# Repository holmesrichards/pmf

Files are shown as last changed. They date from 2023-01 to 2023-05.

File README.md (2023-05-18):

# Pole mixing filter

This is a multimode VCF in Kosmo format based on a [design](https://electricdruid.net/multimode-filters-part-2-pole-mixing-filters) by Electric Druid (ED). It uses pole mixing to achieve multiple filter behaviors.

## Design notes

### Changes from ED design

* 82k resistors (RF) changed to 100k; 91k resistors (RC) to fixed + trimmer.
* Added AC coupling capacitor on input signal to resonance compensation mixer.
* Added resistor on resonance input pin missing from original schematics. Changed its value from 51k to 120k.
* Added op amp buffers and pulldown resistors on LP1–4 after AC coupling capacitors.
* Added second inverting stage on input. Reduced first stage gain to 0.51 and increased output stage gain by the same factor.
* Changed ordering of 1st to 6th mixes.
* In 4P HP mix, changed 4.99k resistor to sum of 2k and 3k.
* Changed BP resistors for unity gain at peak.
* Changed 7th mix to {1, 2, 2, 0, 0} notch.
* Original had incorrect resistances for 8th mix; fixed.
* 7th and 8th mix have enough resistor footprints to implement any desired mix.
* Multiplexer replaced with rotary switch.
* Added header for expansion.

### Discussion

As discussed [here](Docs/tolerances.md), it is important that filter stages have unity DC gain and mixer ratios be correct at a level of about 1% or better, preferably more like 0.1% for the mixer resistors.

The 82k feedback resistors used in the ED design are a puzzle: Per the CEM3320 datasheet, they result in a gain of around 0.82. In the datasheet circuit these resistors are 100k giving gain 0.999. On the breadboard I found some gain variation (even if I matched the resistors), so I replaced the 91k resistors (RI, RC) with fixed + trimmer combinations.

If there is a DC offset on the input signal (if for instance it goes 0 to 5 V), then, due to its being DC coupled to the resonance compensation mixer, turning up the resonance CV would drive the DC offset of the output signal higher. Even with a 0 to 2 V input, the output could exceed 9 V due to the large offset. This is too large: With Vcc = 12 V, maximum output before clipping is about 9 V. Adding a capacitor to AC couple the input signal to the compensation mixer eliminates this problem.

The ED schematics omit a resistor on the resonance input pin. In the comments Tom Wiltshire says this should be 51k. I found this value would cause self oscillation to start up at a very low position of the resonance knob, so changed it to 120k.

With an input of 5 V (or -5 V) or above, the filter stage outputs would try to go to or above about 10 V. I reduced the input gain by a factor of 0.51 to keep below that limit. ±5 V is the standard audio signal range in my synth. Of course if you use two summed inputs they might exceed 5 V, so some additional attenuation may be needed. I also added a second inverting stage with the thought of preserving the phase going into the filter. However there is an inverting stage at the output, so it probably would have been better to leave this second stage out. Not quite sure what I was thinking!

ED's mixers have been re-ordered, just because I felt 2 pole should go before 4 pole. The E96 4.99k resistor has been replaced by E24 2k and 3k in series, because who want to order one resistor from DigiKey that Tayda doesn't carry? The resistor values used by ED in the BP mixers result in peak amplitudes 6 or 12 dB below the input level; I reduced them to get unity gain at the peaks. I wasn't that enthusiastic about the seventh filter — a rather weird combination of things giving rise to a sort of band pass plus notch response — so I replaced it with a second (sharper, deadlier) notch filter.

I didn't see much point in messing around with a multiplexer chip. I used a rotary switch instead. If you really want electronically selectable filter shapes, see the Expansion section below.

The mixers that are not selected by the rotary switch had floating outputs and corrupted the LP1–LP4 signals until I added op amp buffers after the AC coupling capacitors. I believe the same problem would occur with a multiplexer. To avoid bias current charging of the capacitors, I also added 1M resistors to ground between the capacitors and the op amps.

### Choose your own

To accommodate other builders with other preferences (or future me with other preferences), in the last two filters enough resistor (or jumper) footprints have been provided to build almost any mixer allowing whatever filter responses you want. Each of the LP1, LP2, LP3, and LP4 signals has two footprints in series. For example, to re-create ED's seventh filter, [0, 1, 3, 6, 4]: Omit the R<sub>IN</sub> resistor, use 30k and a wire jumper for the two R<sub>LP1</sub> resistors, 10k+jumper for R<sub>LP2</sub>, 2k+3K for R<sub>LP3</sub>, and 7.5k+jumper for R<sub>LP4</sub>. To build the filters shown in the schematic, follow the silkscreen: Use wire jumpers for the jumper footprints and leave the DNF footprints empty.

A catalog of 40+ filters is in [Docs/catalog.md](Docs/catalog.md).

### Expansion

There is an expansion header on the PCB. This could be used to mount a daughterboard giving more mixes. Or it could be used for a ribbon cable connection to an expansion module, which could e.g. provide user-changeable mixes (5 rotary switches?) or a microcontroller-based variable mixer, potentially even with CV input to switch mixes. This repo includes a design for a daughterboard providing four additional builder-defined mixes. As with filters 7 and 8 on the main module, there are two footprints for each of the LP1, LP2, LP3, and LP4 signals and you can populate both with resistors, use one resistor and one jumper, or omit both to get the mixes you desire. This daughterboard has not been built or tested yet.

### Filters

The filters are as follows. Numbers indicate coefficients for input, -LP1, LP2, -LP3, and LP4 mixing.

* 0, 0, 1, 0, 0 — 2 pole low pass
* 0, 0, 0, 0, 1 — 4 pole low pass
* 1, 2, 1, 0, 0 — 2 pole high pass
* 1, 4, 6, 4, 1 — 4 pole high pass
* 0, 2, 2, 0, 0 — 2 pole band pass
* 0, 0, 4, 8, 4 — 4 pole band pass
* 1, 2, 2, 0, 0 — Notch A
* 1, 2, 2, 2, 2 — Notch B

Here are Bode plots for these filters:

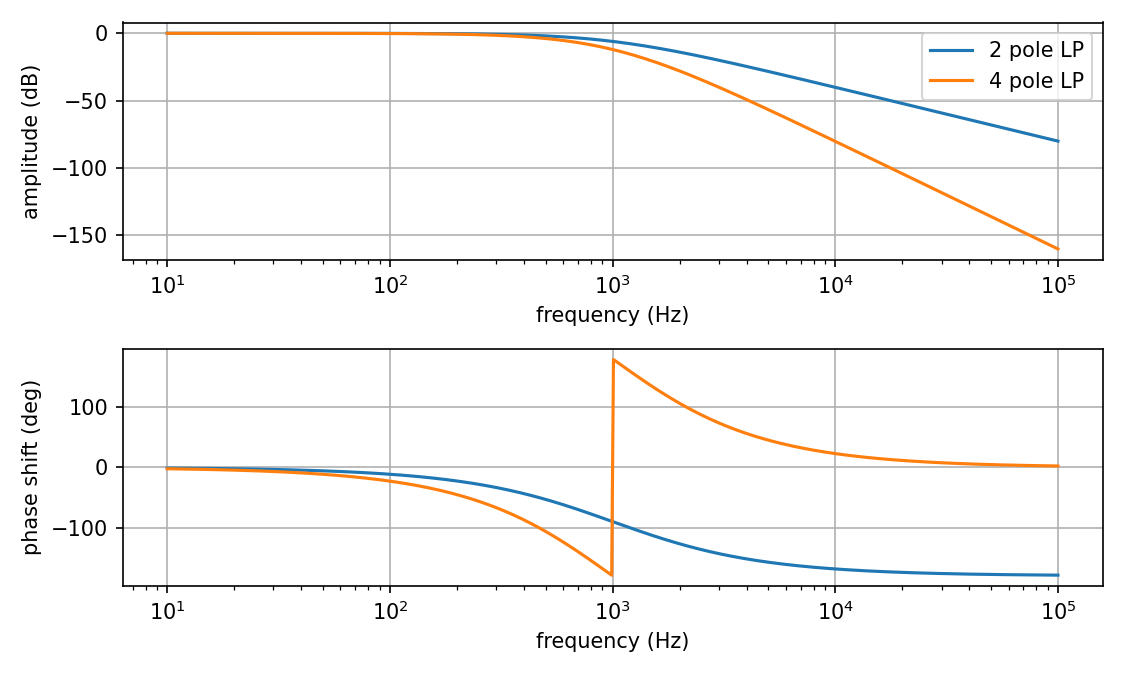
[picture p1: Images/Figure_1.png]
Low pass

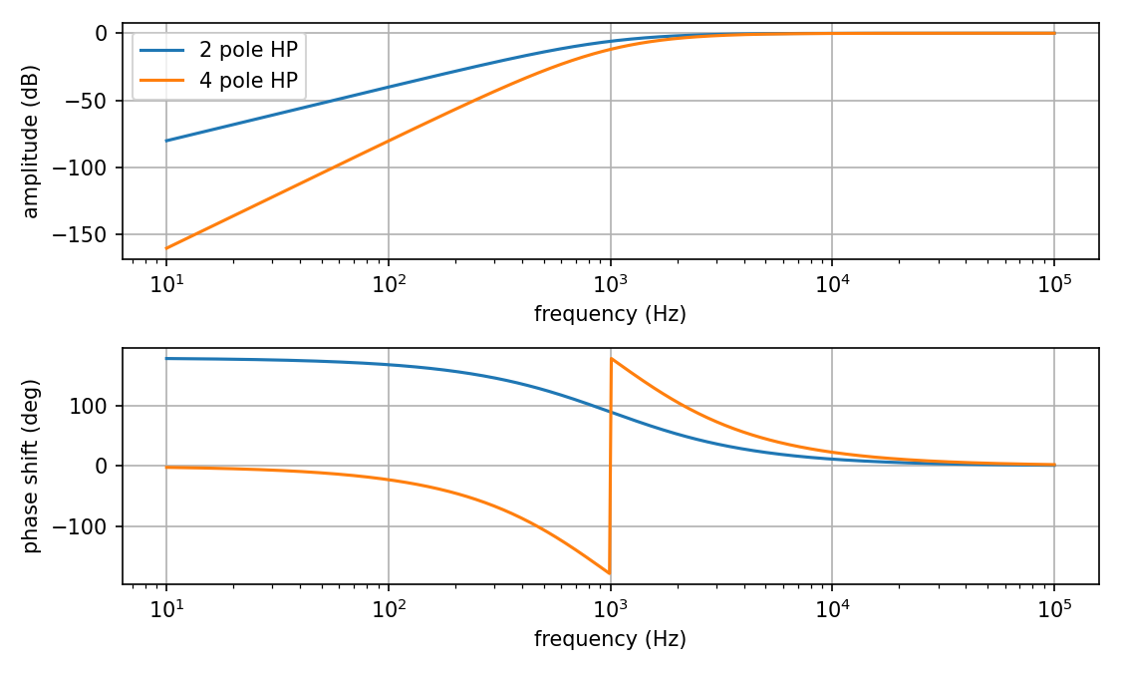
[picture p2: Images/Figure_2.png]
High pass

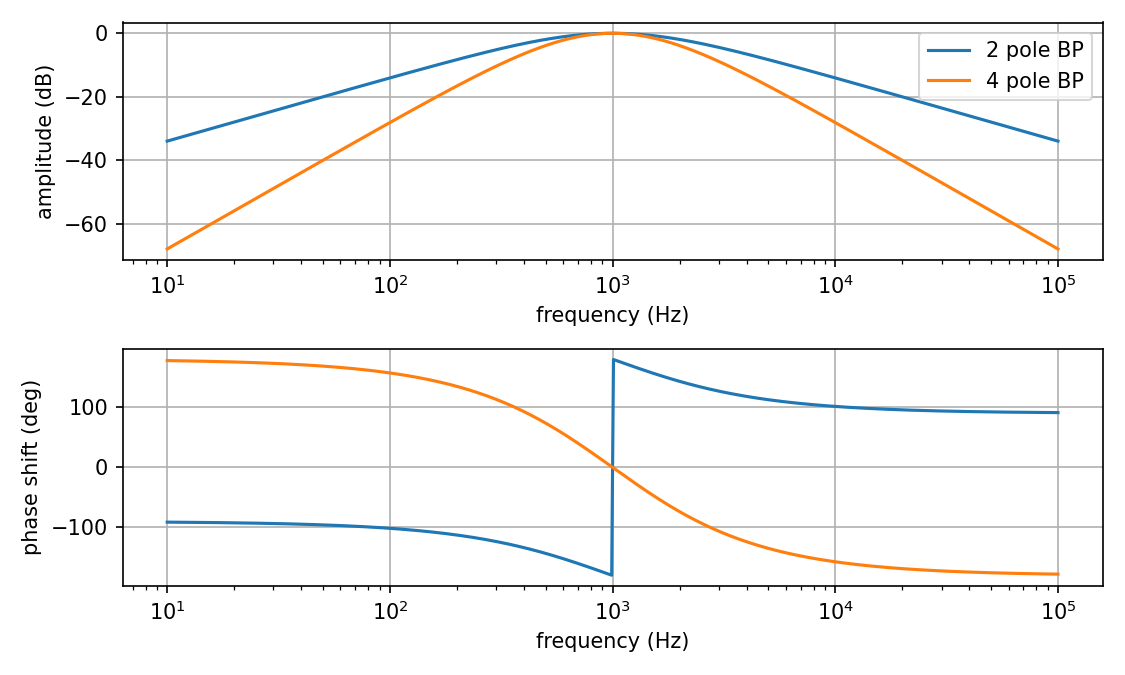
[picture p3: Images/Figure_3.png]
Band pass

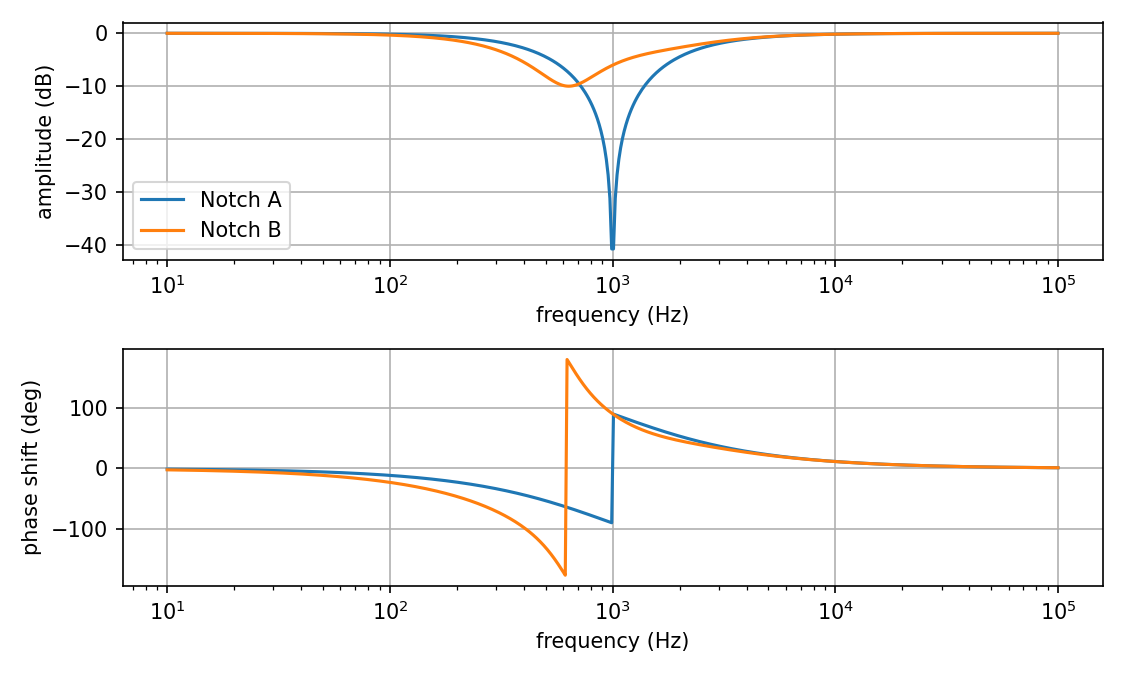
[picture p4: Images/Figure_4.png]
Notch


### Cancellation and tolerances

See discussion [here](Docs/tolerances.md).

## Software

The plots above were produced with a Python script included in this repo's Software folder. For a usage example see plots.sh in that folder. Libraries matplotlib, numpy, sys, and re are required. 

For the formulas for pole mixing upon which these plots are based, see [https://expeditionelectronics.com/Diy/Polemixing/math](https://expeditionelectronics.com/Diy/Polemixing/math). I believe there are some errors: the formulas for the imaginary parts of the numerator and denominator should have the opposite sign.

## Current draw
? mA +12 V, ? mA -12 V

## Photos

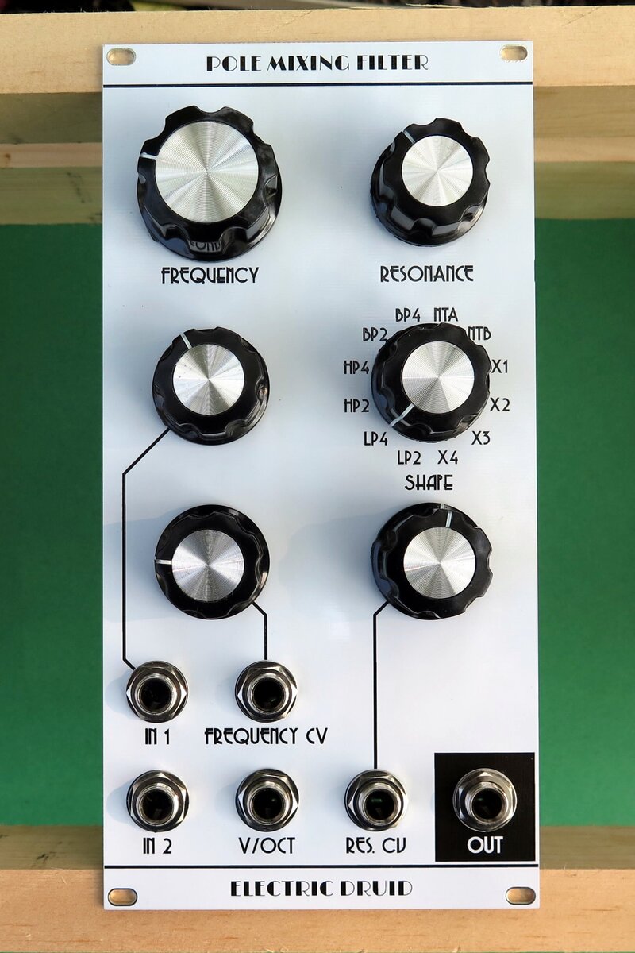
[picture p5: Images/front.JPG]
Front

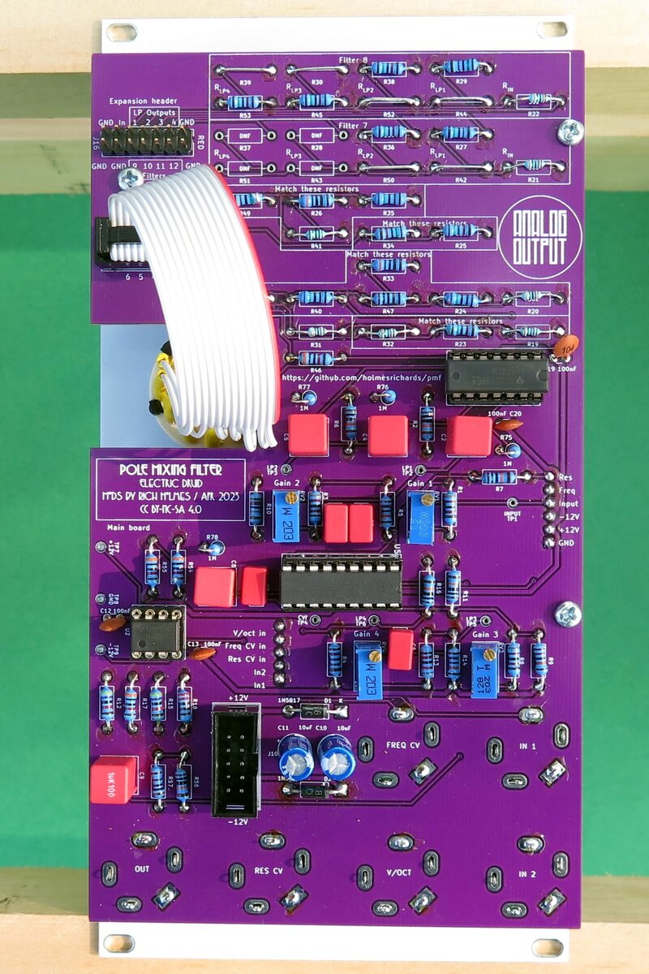
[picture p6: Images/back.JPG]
Back


## Documentation

* [Schematic](Docs/pmf_schematic.pdf)
* PCB layout: [front of board 1](Docs/Layout/pmf_B1/pmf_B1_front.svg), [back of board 1](Docs/Layout/pmf_B1/pmf_B1_back.svg), [front of board 2](Docs/Layout/pmf_B2/pmf_B2_front.svg), [back of board 2](Docs/Layout/pmf_B2/pmf_B2_back.svg)
* [BOM](Docs/BOM/pmf_bom.md)
* [Daughterboard schematic](Docs/pmf_daughter_schematic.pdf)
* Daughterboard PCB layout: [front](Docs/Layout/pmf_daughter/pmf_daughter_front.svg), [back](Docs/Layout/pmf_daughter/pmf_daughter_back.svg)
* [Daughterboard BOM](Docs/BOM/pmf_daughter_bom.md)
* [Blog post](https://analogoutputblog.wordpress.com/2023/05/04/pole-mixing-filter/)

## GitHub repository

* [https://github.com/holmesrichards/pmf](https://github.com/holmesrichards/pmf)

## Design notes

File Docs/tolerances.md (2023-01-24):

# Notes on cancellation and tolerances

How do you get a high pass filter, or band pass, or any filter that goes to zero amplitude output at zero frequency, with a combination of low pass filters? Answer: By cancellation. Two of the poles are inverted and their contribution cancels that of the other poles and input. For example, a 1 pole HP is input minus 1 pole LP. At low frequency these are supposed to be equal magnitude and phase and their difference is zero.

But that means sensitivity to errors. Quoting the Electric Druid page, "These are proper mixed responses that need careful matching of the outputs. If the outputs are not well matched, the cancellation of the signal in the stop band will not be good, and you’ll have a highpass filter with some “leakage” of low frequencies. For musical use, this may well not be that important."

Looking at the [formulas](https://expeditionelectronics.com/Diy/Polemixing/math), we see there's a term in the real part of the numerator equal to A-B+C-D+E. With [1, 4, 6, 4, 1] this equals 0. But suppose there is a 1% error in the third coefficient? With [1, 4, 6.06, 4, 1] this becomes 0.06, which then is the dominant term in the numerator at low frequency. So instead of the amplitude going to zero at DC, it levels off at 6% of the input amplitude.

In addition, at nonzero frequency, if the error causes a sign change, this corresponds to a 180° phase flip at that frequency.

Below are Bode plots for a perfect 4-pole high pass filter, with coefficients [A, B, C, D, E] = [1, 4, 6, 4, 1], and filters with each coefficient changed by 1%. The corner frequency is 1 kHz.

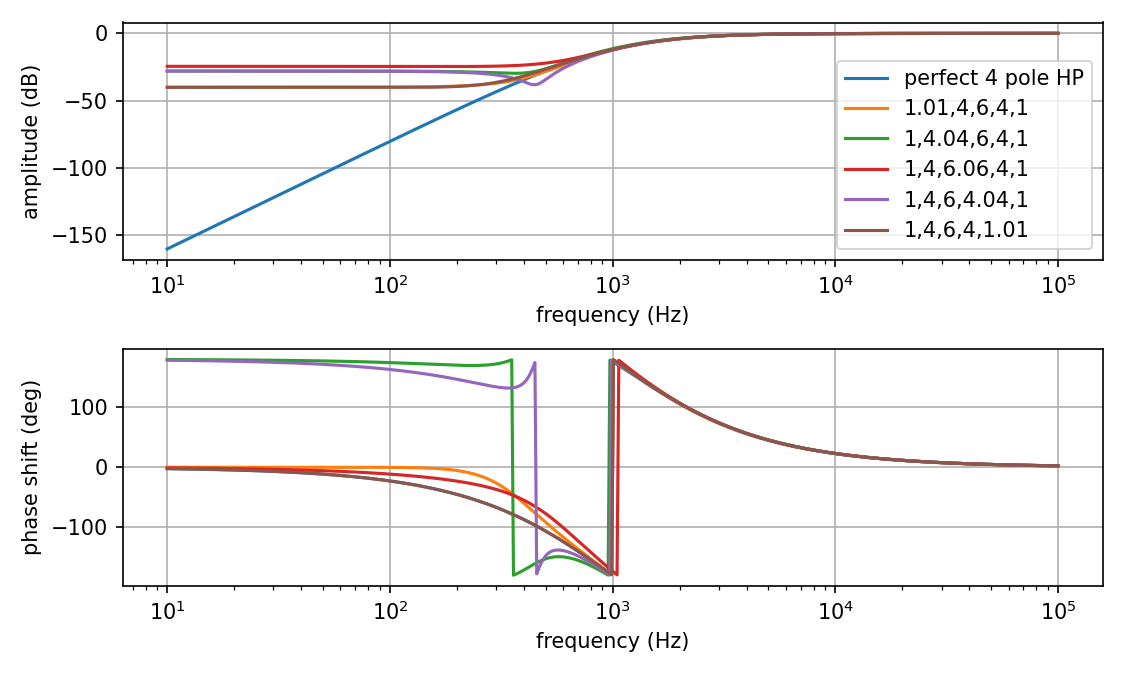
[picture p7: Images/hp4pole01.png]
HP4_1%


Note how with an error in the second or fourth coefficient, in addition to the leveling off of the amplitude at DC, the phase flips 180° at around 300 to 500 Hz. Under some circumstances this could be problematic if mixing with other signals of the same frequency.

Even with a 0.1% error the amplitude below about 200 Hz is significantly higher than with perfect coefficients, but probably not large enough to be objectionable. The phase flip occurs about 200 Hz, and is also probably unimportant at this small amplitude.

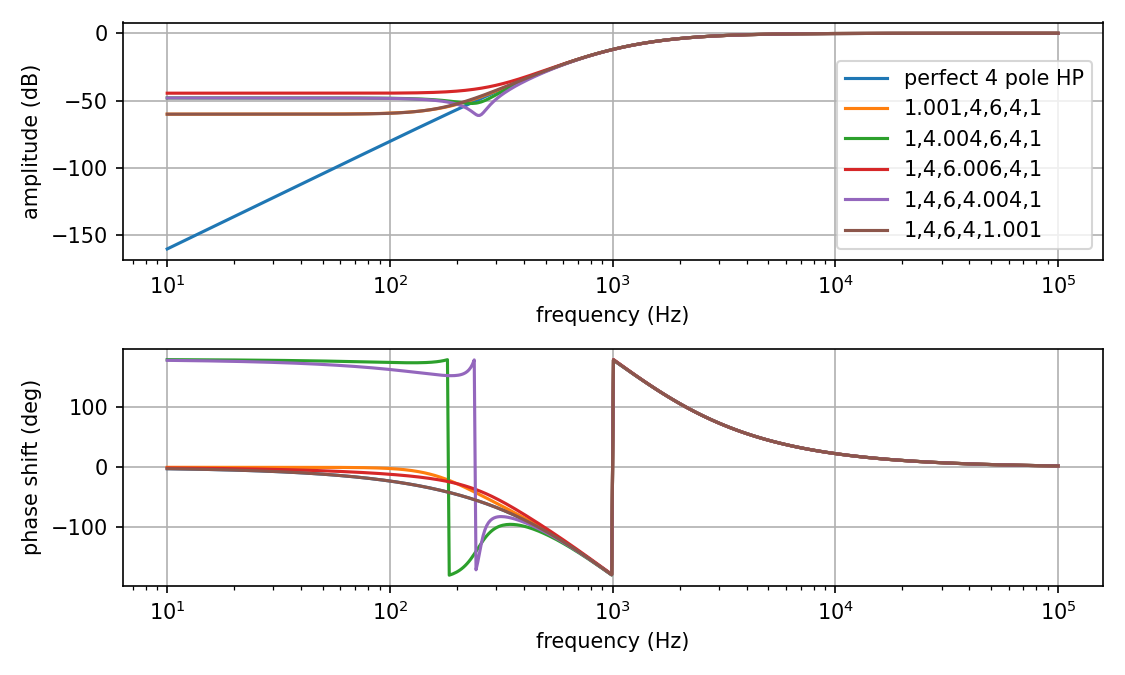
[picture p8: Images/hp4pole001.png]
HP4_0.1%


For the lower order HP filters the same thing happens but the sensitivity at DC to exact coefficients is lower. With 1% error the effect on the amplitude is pretty much negligible down to 10 Hz for 1-pole HP.

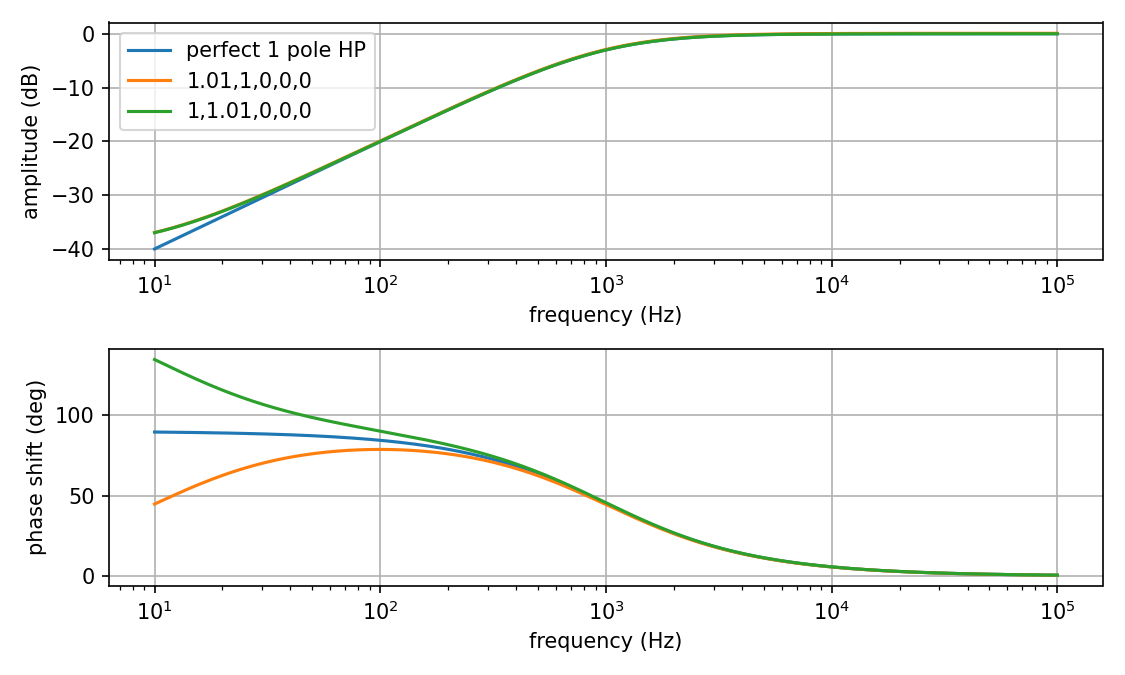
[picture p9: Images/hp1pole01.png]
HP1_1%


With 0.1% errors the changes are certainly negligible:

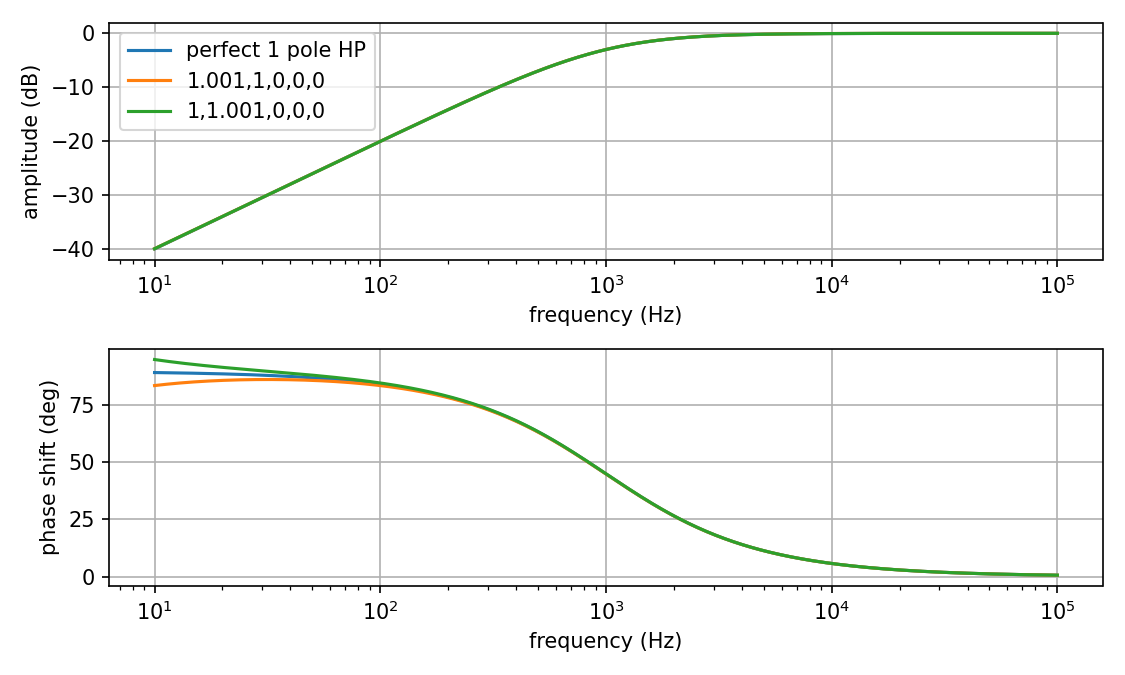
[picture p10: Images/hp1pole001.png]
HP1_0.1%


However, things get worse with the 2-pole HP. Here there is a leveling off below about -35 dB and a phase inversion at 100 Hz with a 1% error in the first or third coefficient.

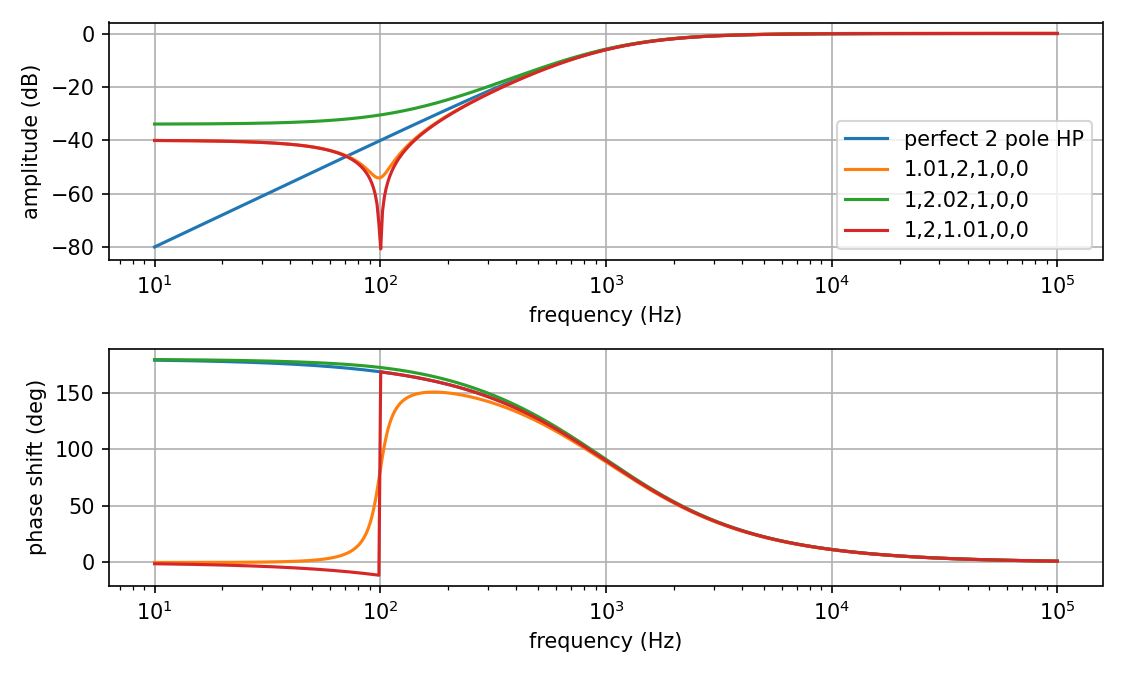
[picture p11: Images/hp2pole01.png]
HP2_1%


With 0.1% errors the phase inversion moves down to about 30 Hz:

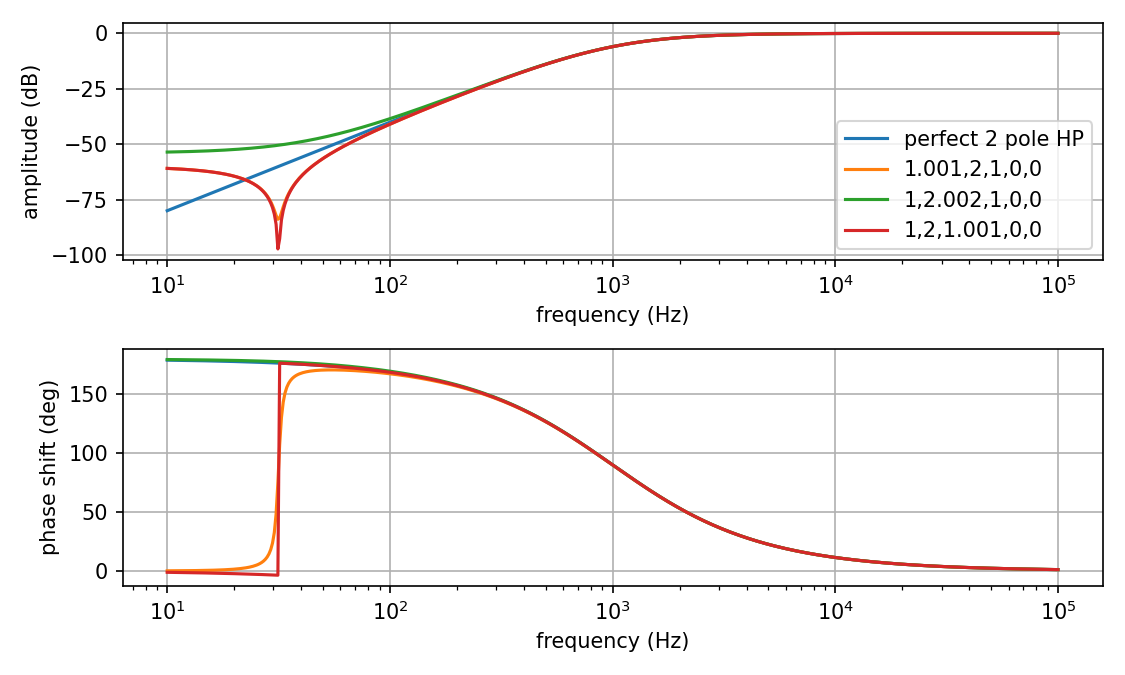
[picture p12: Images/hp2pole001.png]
HP2_0.1%


Similarly for the band pass filters. 2-pole, 1% errors is okay:

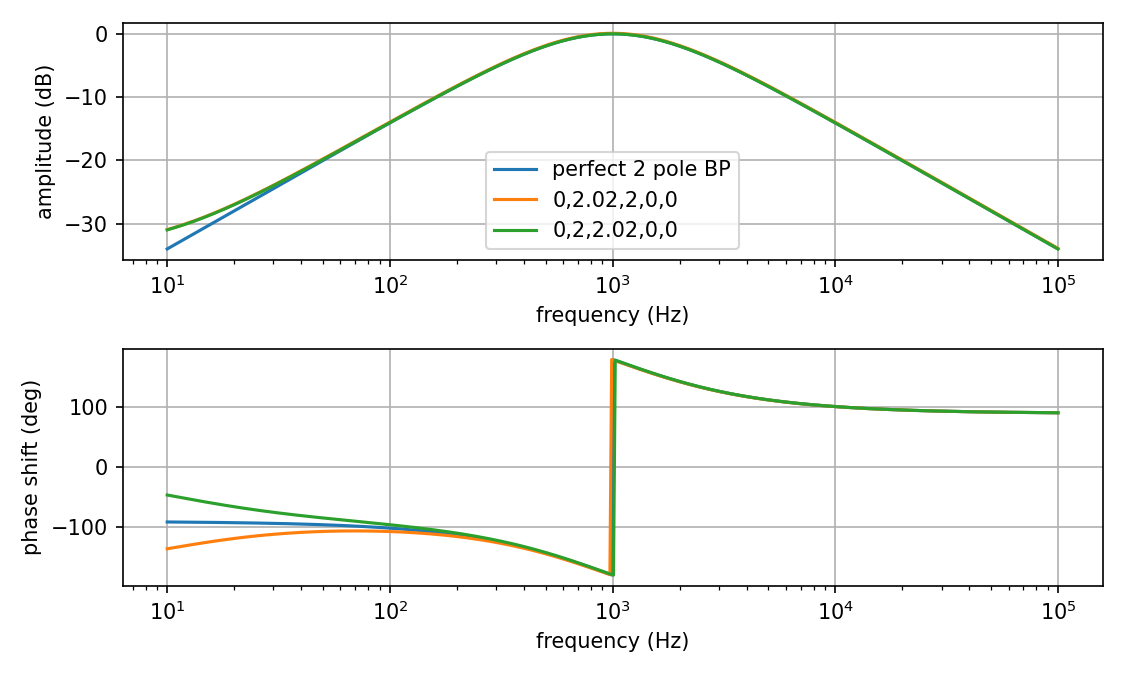
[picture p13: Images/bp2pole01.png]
BP2_1%


and 2-pole, 0.1% errors is fine:

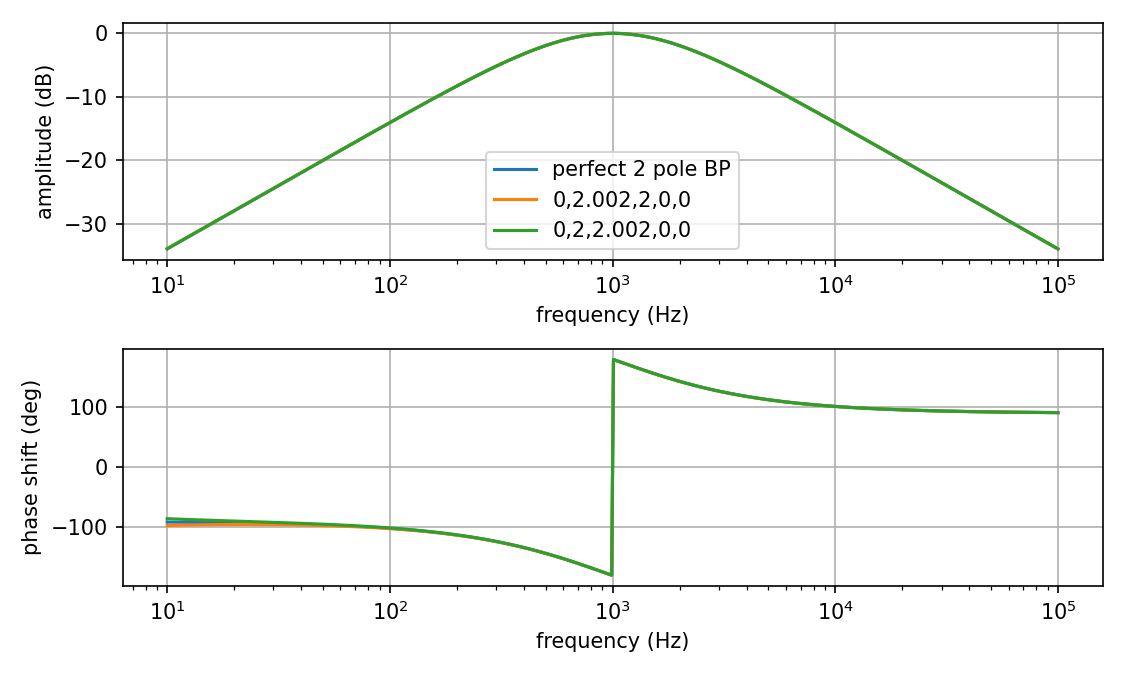
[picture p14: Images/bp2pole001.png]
BP2_0.1%


But 4-pole, 1% errors is trouble:

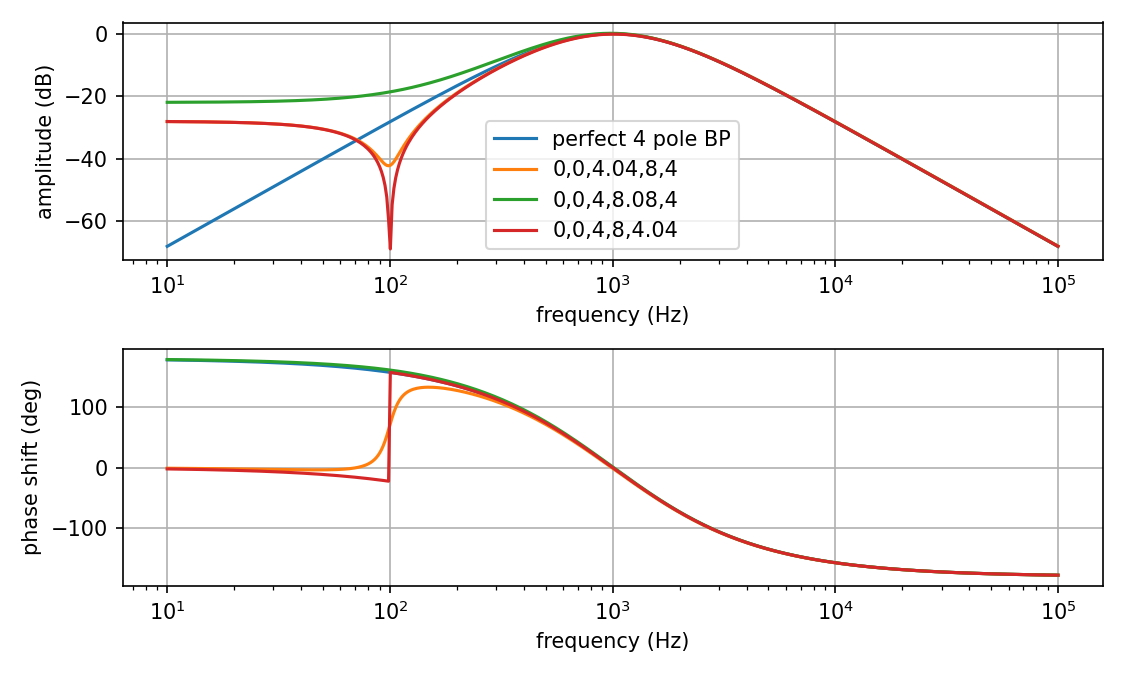
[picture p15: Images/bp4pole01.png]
BP4_1%


while 4-pole, 0.1% errors is good at audible frequencies (with 1kHz corner):

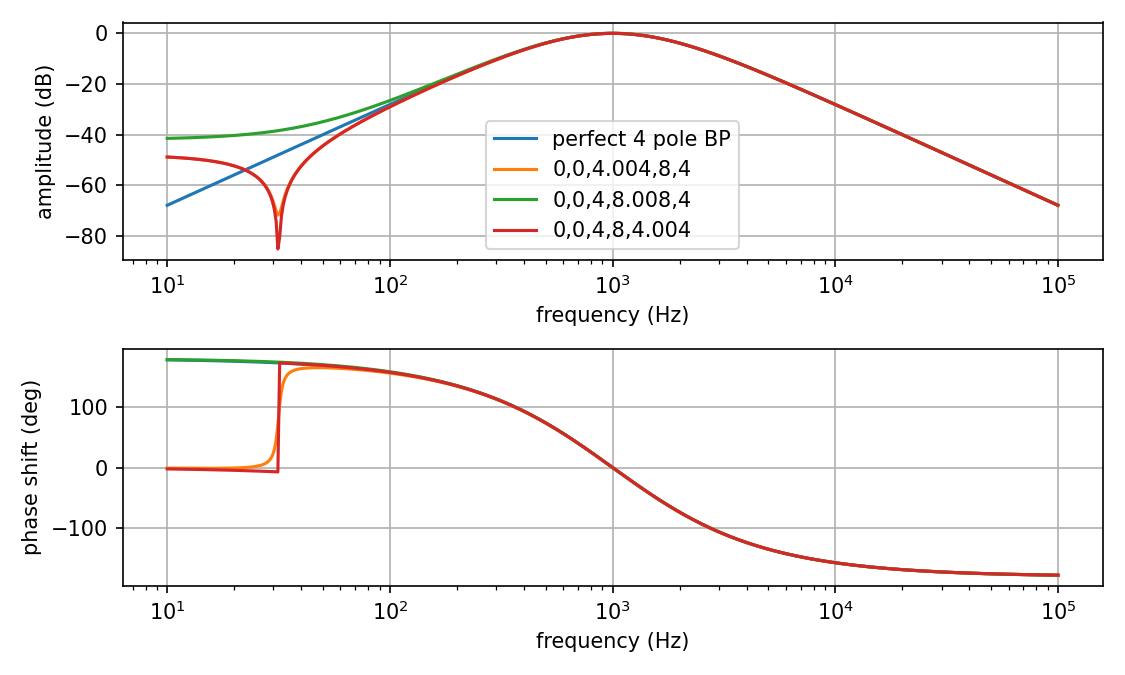
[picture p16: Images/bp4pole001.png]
BP4_0.1%


These plots illustrate cases where *one* coefficient is inaccurate, but in reality all five are likely to vary randomly if randomly chosen resistors are used in the mixers. 1% tolerance is probably not good enough, at least for higher order high pass and band pass filters. Hand matching resistors at more like the 0.1% level is recommended.

The filter gains, too, should be calibrated to be unity with high precision. But in fact the gains vary over the range of the frequency control voltage by as much as ~2%. However, these shifts are correlated: All stages experience approximately the same size shift in the same direction. Then the gain errors in the even stages (with positive coefficients in the pole sums) tend to cancel those in the odd stages (with negative coefficients). In addition most of the gain shift occurs at higher, less useful values of the control voltage. So as long as the stages are calibrated to unity gain at moderate control voltage, the effects of the gain shift should generally be quite tolerable.

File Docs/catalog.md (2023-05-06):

# Catalog

Coefficients and names from [https://expeditionelectronics.com/Diy/Polemixing](https://expeditionelectronics.com/Diy/Polemixing)

* [0, 1, 0, 0, 0] LP1
* [0, 0, 1, 0, 0] LP2
* [0, 0, 0, 1, 0] LP3
* [0, 0, 0, 0, 1] LP4
* [0, 0, 0, 3, 3] HP1 + LP3
* [0, 0, 3, 3, 0] HP1 + LP2
* [0, 2, 2, 0, 0] BP2
* [0, 0, 4, 8, 4] BP4
* [0, 3, 9, 9, 3] HP3 + LP1
* [0, 3, 6, 3, 0] HP2 + LP1
* [0, 3, 6, 4, 1] BP Alt.
* [1, 1, 0, 0, 0] HP1
* [1, 2, 1, 0, 0] HP2
* [1, 3, 3, 1, 0] HP3
* [1, 4, 6, 4, 1] HP4
* [1, 2, 2, 0, 0] Notch
* [.5, 1, 2.5, 0, 0] Res Before Notch
* [1.5, 3, 2, 0, 0] Res After Notch
* [1, 2, 2, 2, 2] Notch B
* [1, 3, 6, 4, 1] Notch C
* [0, 1, 2, 2, 0] LP1 + Notch A
* [0, 4, 8, 5, 0] LP1 + Notch B (octave down)
* [0, 3, 6, 4, 0] LP1 + Notch C
* [0, 0, 1, 2, 2] LP2 + Notch A
* [0, 0, 4, 8, 5] LP2 + Notch B (octave down)
* [0, 0, 3, 6, 4] LP2 + Notch C
* [0, 0, .3, .6, 1.5] LP2 + Notch D
* [0, 2, 4, 3, 0] LP1 Notch B
* [0, 3, 9, 10, 4] BP Notch Offset Left
* [0, 4, 12, 16, 8] BP Notch
* [0, 1, 3, 6, 4] BP Notch Offset Right
* [0, 1, 3, 7, 5] BP Notch Octave Up
* [1, 3, 4, 2, 0] HP + Notch A
* [1, 3, 6, 4, 0] HP + Notch B
* [1, 4, 7, 6, 2] HP2 + Notch A
* [1, 4, 8, 8, 3] HP2 + Notch B
* [1, 4, 9, 10, 4] HP2 + Notch C
* [1, 4, 10, 12, 5] HP2 + Notch D
* [1, 4, 10, 12, 6] Double Notch A (almost Octaves)
* [1, 4, 10.25, 12.5, 6.25] Double Notch Octaves
* [1, 4, 11, 14, 7] Double Notch B
* [1, 4, 12, 16, 8] Double Notch C (Dixon)
* [1, 4, 14, 20, 10] Double Notch D
* [1, 4, 15, 22, 11] Double Notch (approx. 3rd Harmonic)
* [.1, .6, 1.1, 2.8, 3.2] 20db LP shelf

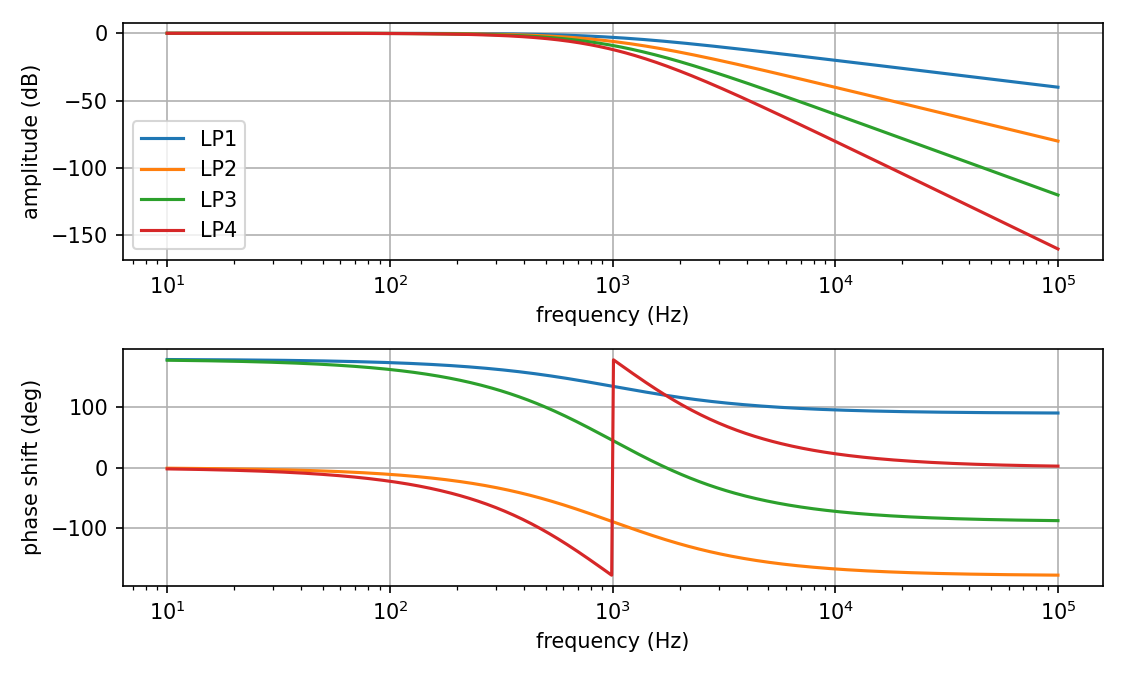
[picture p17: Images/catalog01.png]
catalog01

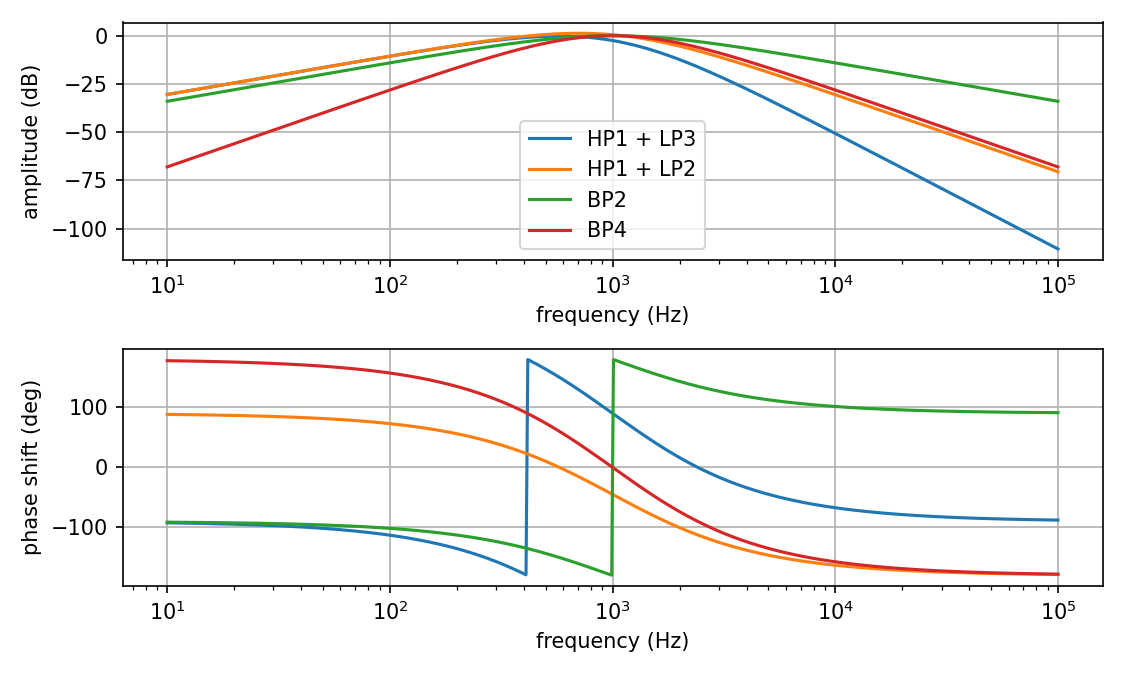
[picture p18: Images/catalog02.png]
catalog02

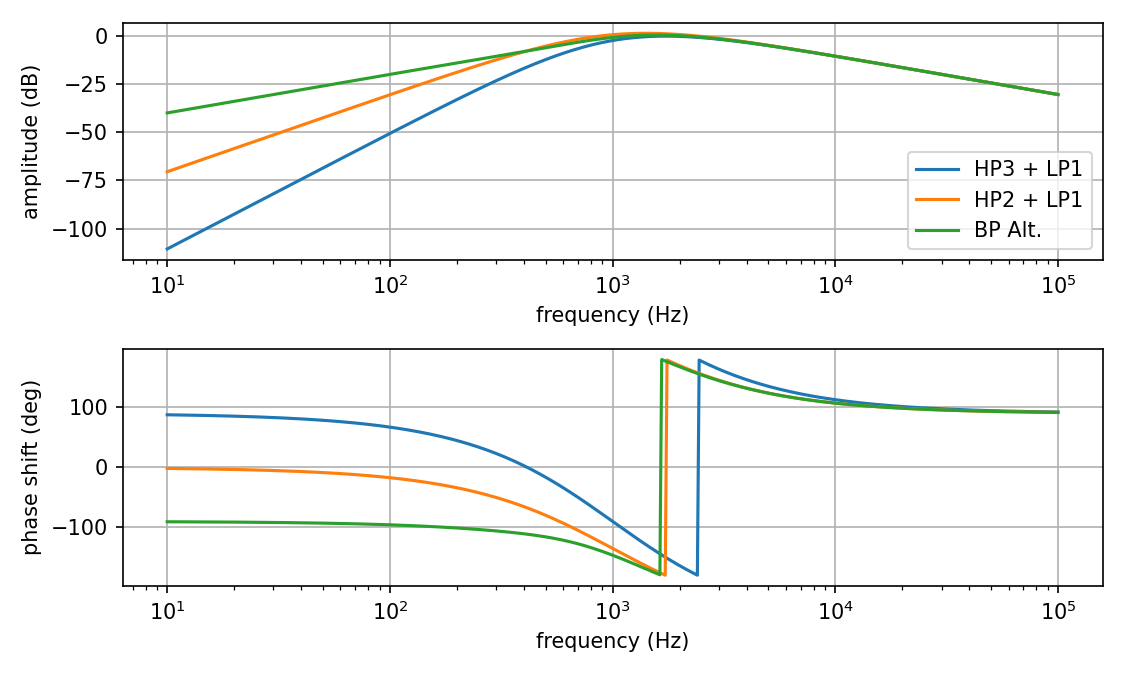
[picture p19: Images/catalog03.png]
catalog03

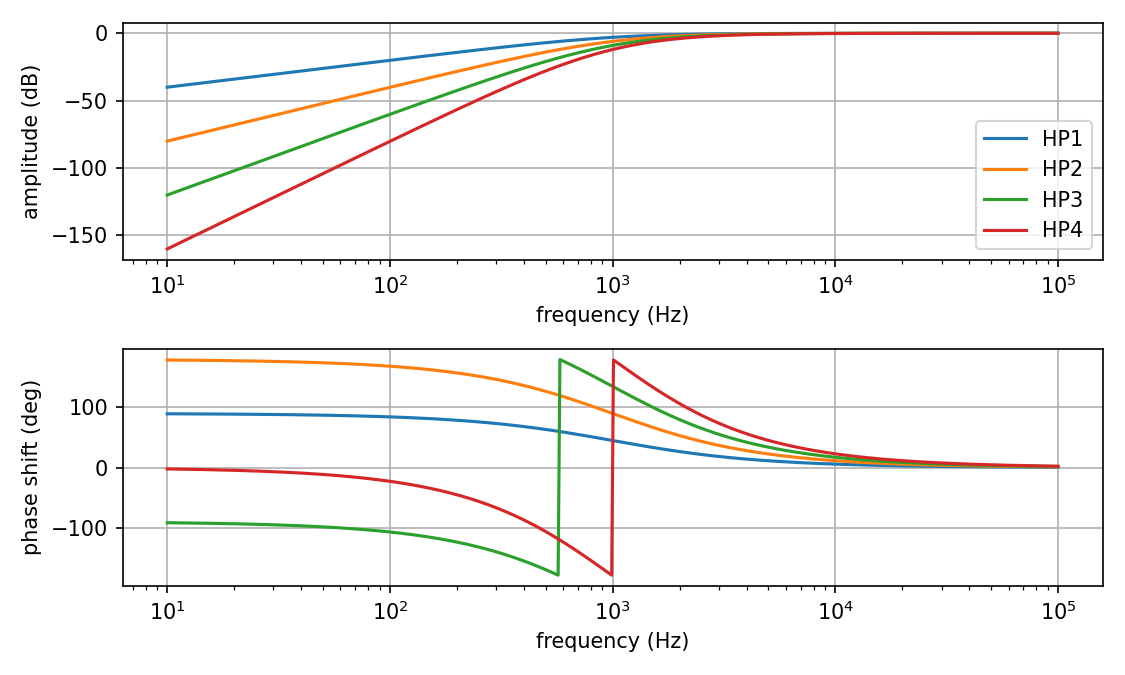
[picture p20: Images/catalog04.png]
catalog04

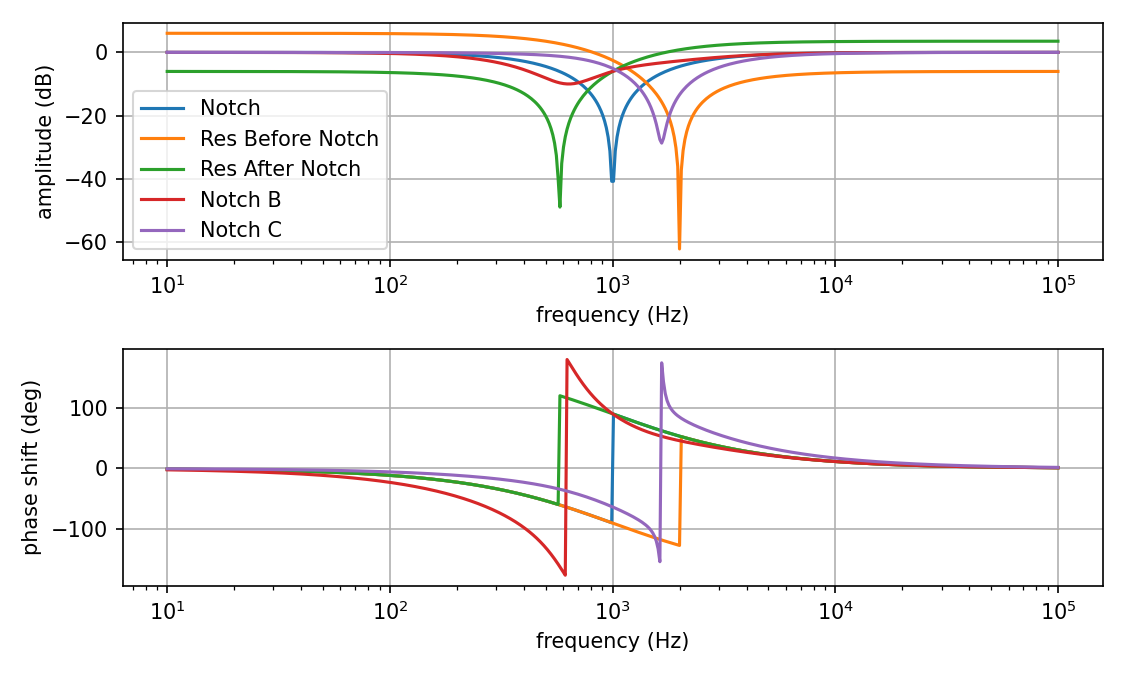
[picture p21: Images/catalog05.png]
catalog05

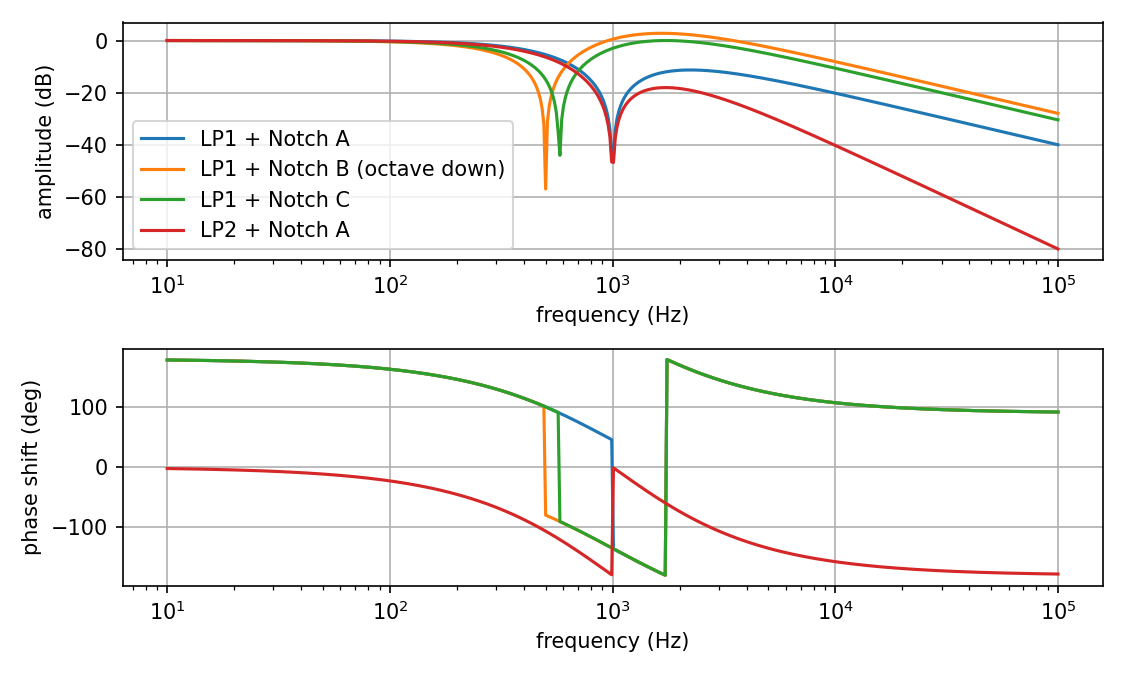
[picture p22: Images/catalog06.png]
catalog06

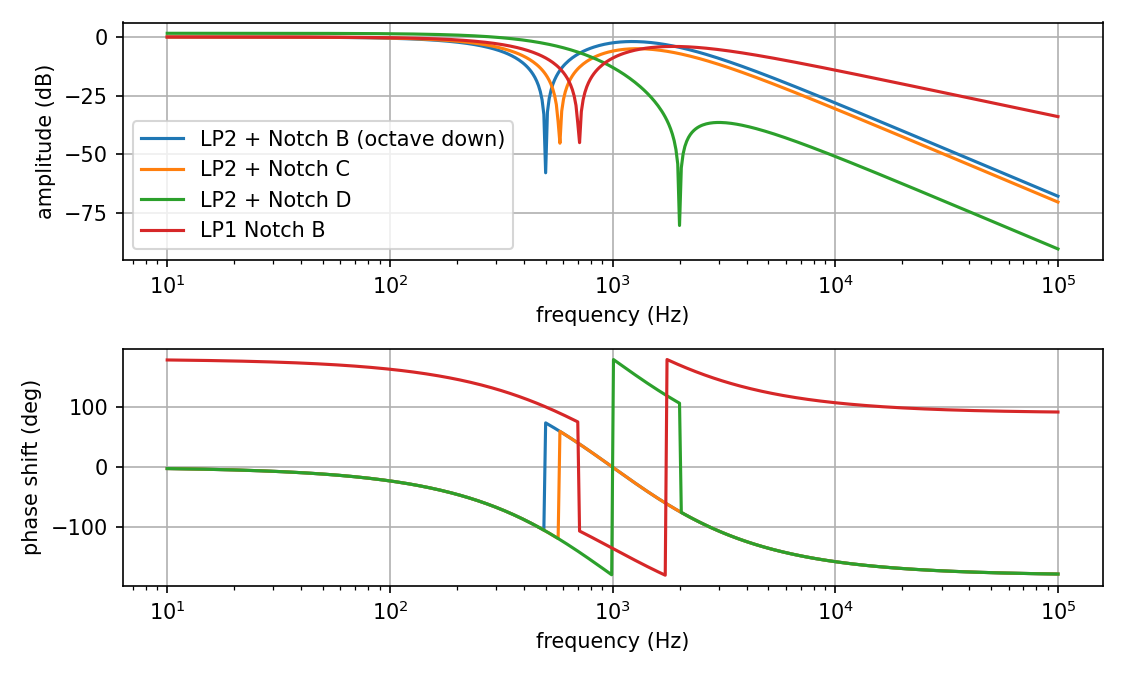
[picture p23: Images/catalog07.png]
catalog07

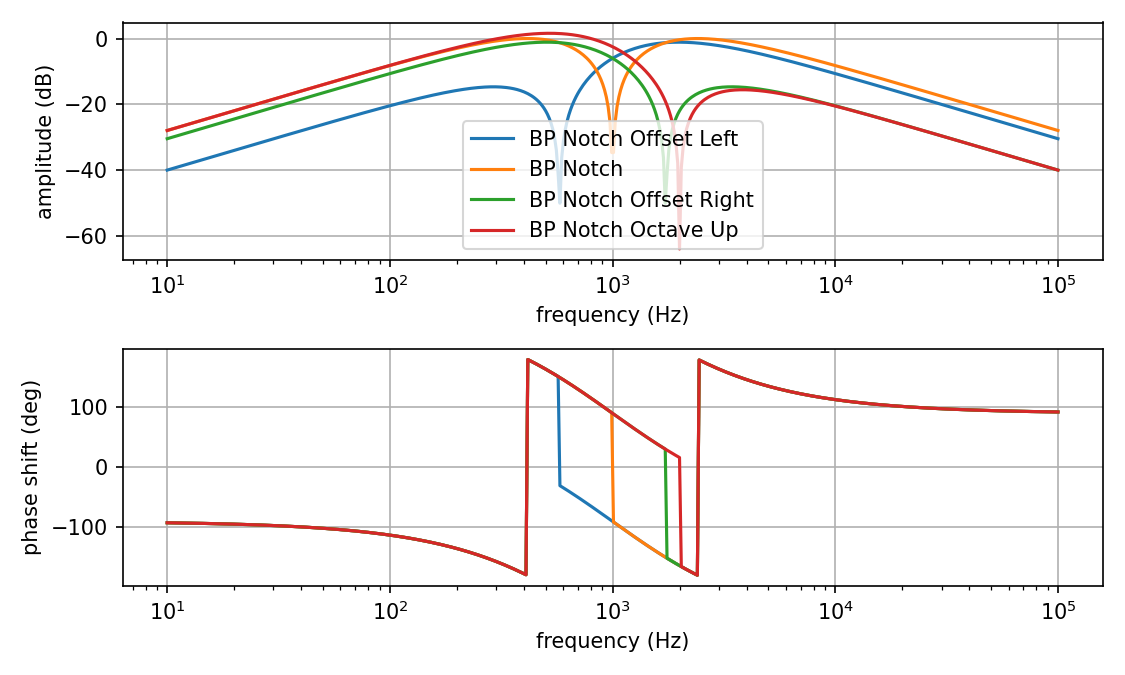
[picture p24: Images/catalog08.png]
catalog08

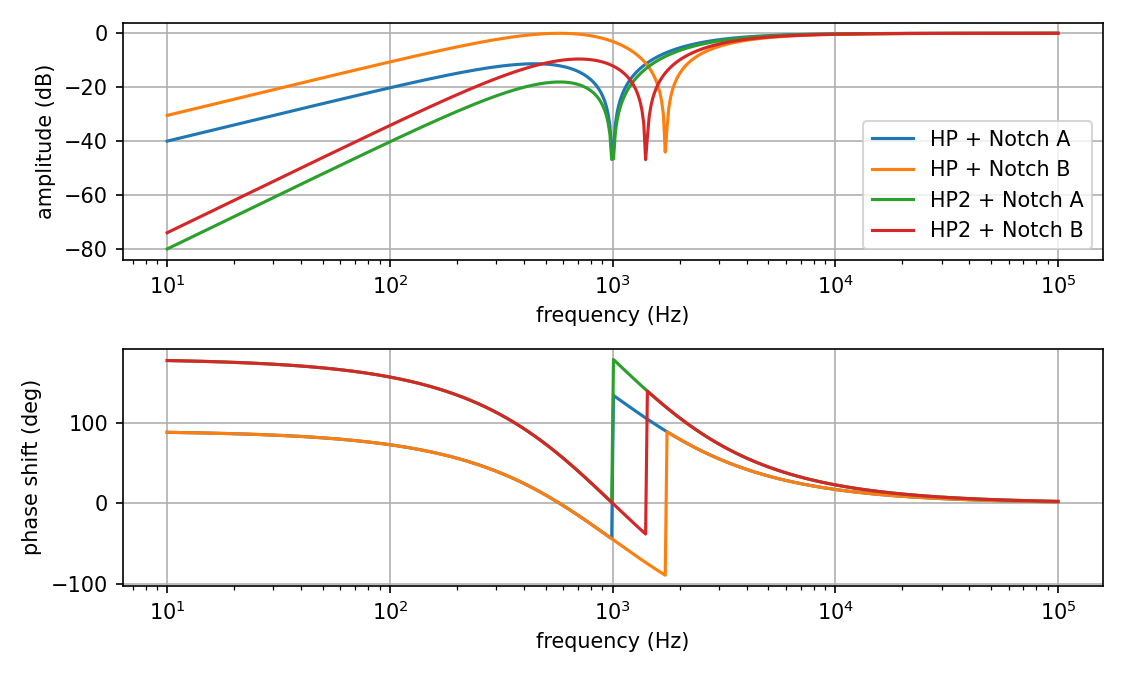
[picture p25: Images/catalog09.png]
catalog09

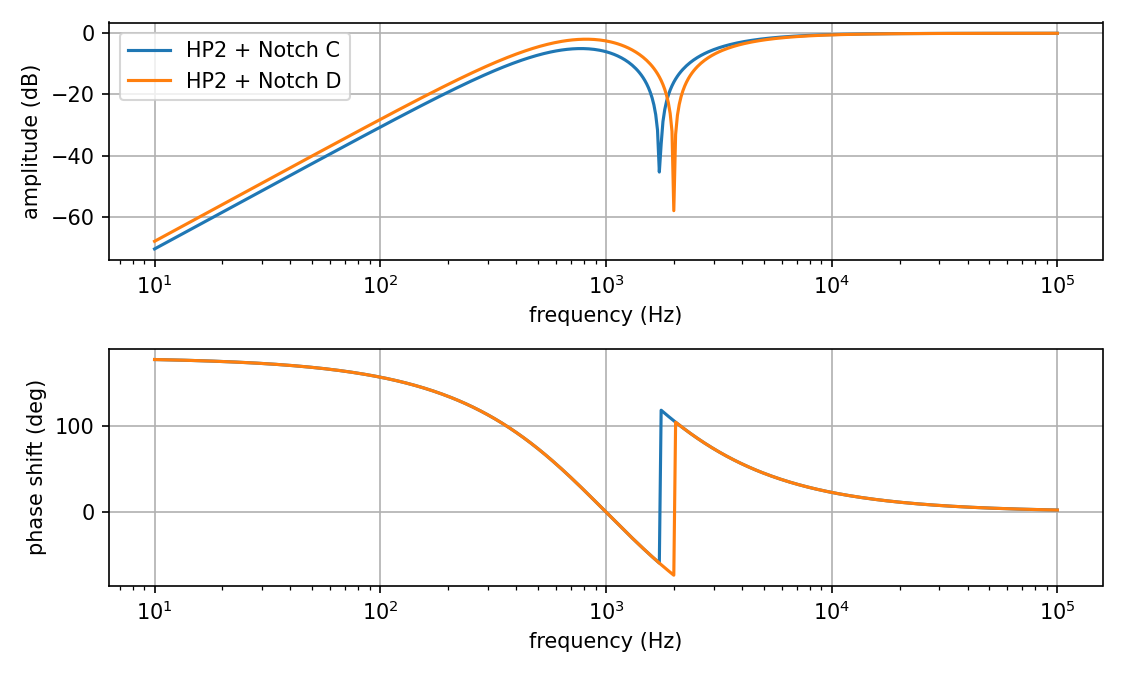
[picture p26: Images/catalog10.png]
catalog10

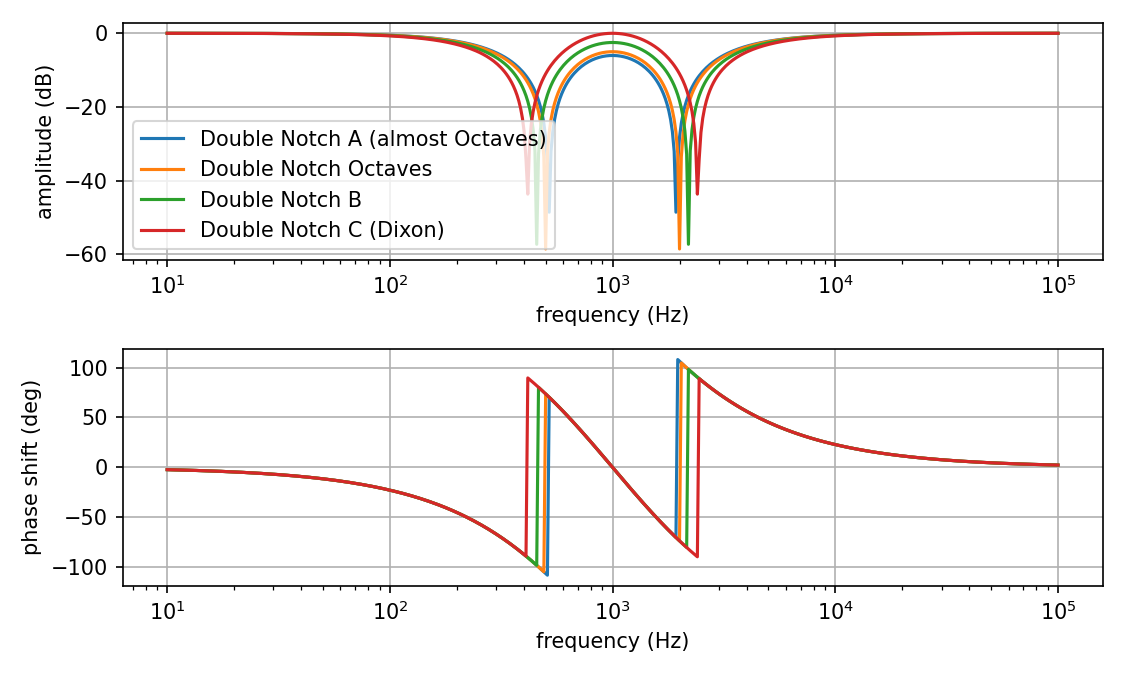
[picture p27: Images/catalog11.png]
catalog11

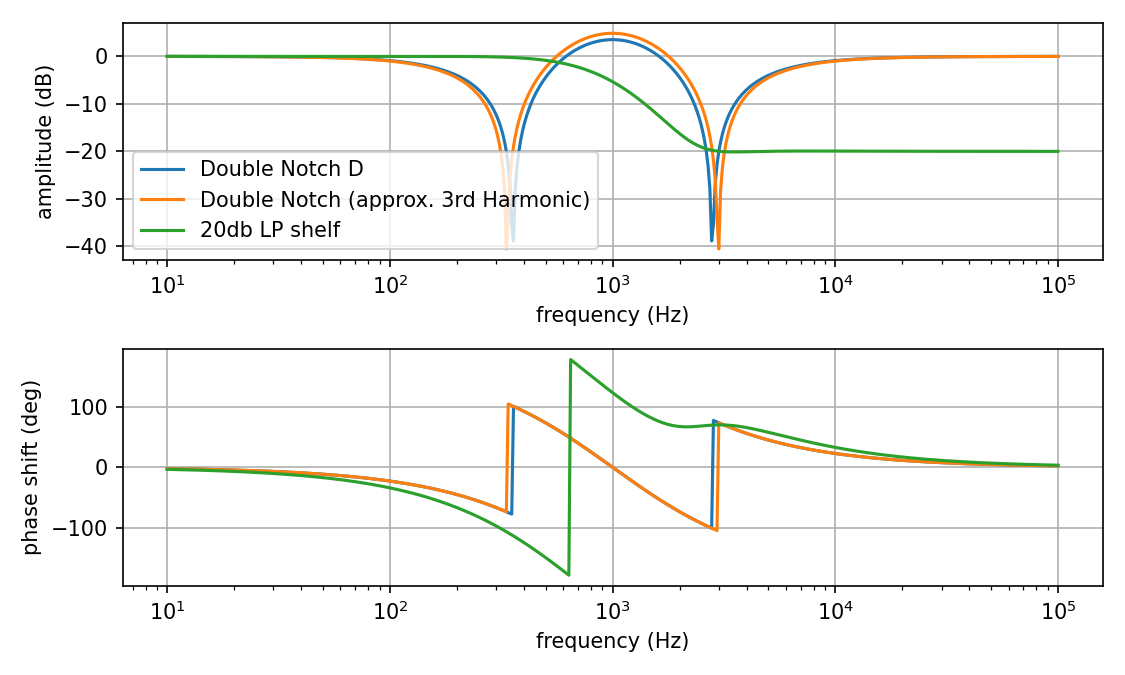
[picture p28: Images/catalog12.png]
catalog12


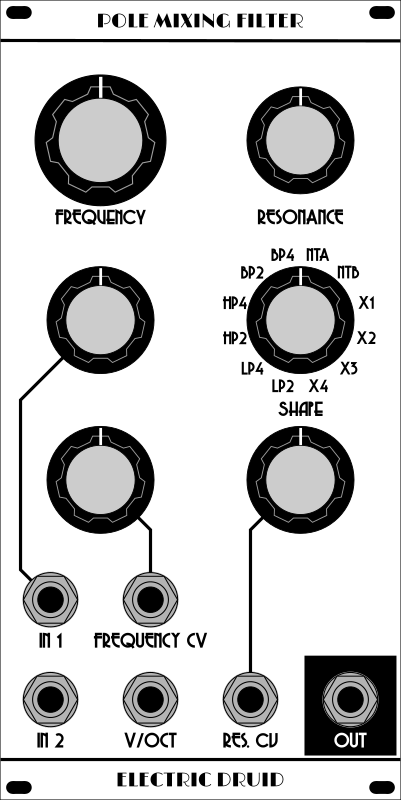
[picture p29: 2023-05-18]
Images/pmf_panel.png

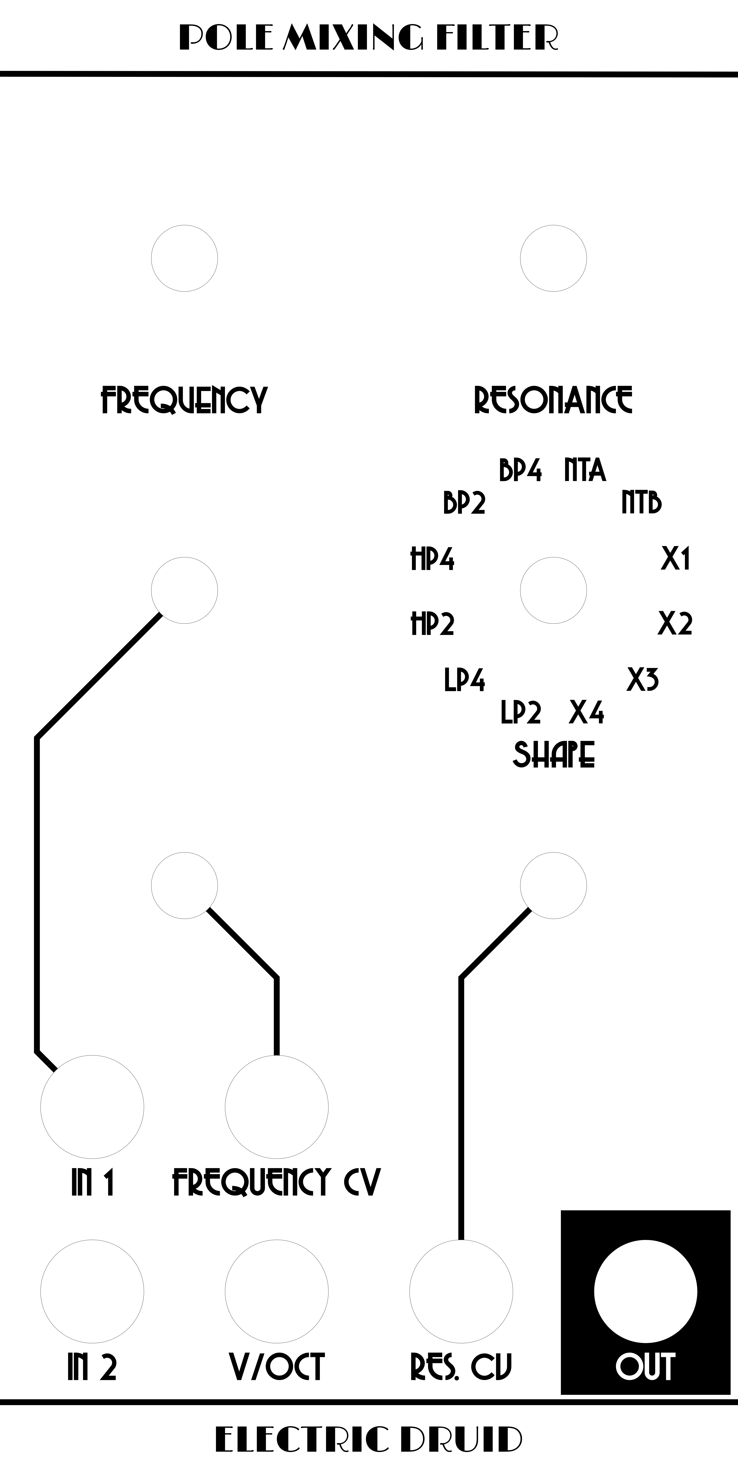
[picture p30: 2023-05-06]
Images/pmf_panel_art.png

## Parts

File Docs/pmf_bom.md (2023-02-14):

# pmf.kicad_sch BOM

Mon 13 Feb 2023 10:27:23 PM EST

Generated from schematic by Eeschema 7.0.0

**Component Count:** 143

| Refs | Qty | Component | Description | Manufacturer | Part | Vendor | SKU |
| ----- | --- | ---- | --- | ---- | ---- | ---- | ---- |
| C1, C3, C5, C7, C14 | 5 | 330pF | Polypropylene film capacitor, 5 mm lead spacing | WIMA | FKP2D003301D00JSSD | Tayda | 1928-1236-ND |
| C2, C4, C6, C8, C9 | 5 | 1uF | Film capacitor, 5 mm lead spacing |  |  | Tayda |  |
| C10, C11 | 2 | 10uF | Electrolytic capacitor, 2.5 mm lead spacing |  |  | Tayda | A-4349 |
| C12, C13, C15–18 | 6 | 100nF | Ceramic capacitor, 2.5 mm lead spacing |  |  | Tayda | A-553 |
| D1, D2 | 2 | 1N5817 | Schottky Barrier Rectifier Diode, DO-41 |  |  | Tayda | A-159 |
| D3, D4 | 2 | 1N4148 | Standard switching diode, DO-35 |  |  | Tayda | A-157 |
| J1 | 1 | Conn_01x06_Pin | 2.54 mm pin header, 1x6 positions |  |  |  |  |
| J2 | 1 | Conn_01x05_Pin | 2.54 mm pin header, 1x5 positions |  |  |  |  |
| J3 | 1 | Conn_01x06_Socket | 2.54 mm pin socket, 1x6 positions |  |  |  |  |
| J4 | 1 | Conn_01x05_Socket | 2.54 mm pin socket, 1x5 positions |  |  |  |  |
| J5–9, J12 | 6 | AudioJack2 | Audio Jack, 2 Poles (Mono / TS) |  |  | Tayda | A-1121 |
| J10 | 1 | Synth_power_2x5 | Pin header 2.54 mm 2x5 |  |  | Tayda | A-2939 |
| J11 | 1 | Conn_02x07_Odd_Even | Shrouded IDC header, 2x7 positions |  |  |  |  |
| J13 | 1 | Conn_02x07_Odd_Even | IDC connector, 2x7 positions |  |  |  |  |
| J14 | 1 | Conn_02x07_Odd_Even | 2.54 mm pin header, 2x7 positions |  |  |  |  |
| J15, J16 | 2 | DIP-8 | 8 pin DIP socket |  |  |  |  |
| J17 | 1 | DIP-14 | 14 pin DIP socket |  |  |  |  |
| J18 | 1 | DIP-18 | 18 pin DIP socket |  |  |  |  |
| R1, R3, R8, R13 | 4 | 82k | Resistor |  |  | Tayda |  |
| R2, R6, R7, R11, R16, R56, R58–62, R64, R65, R67, R68 | 15 | 100k | Resistor |  |  | Tayda |  |
| R4 | 1 | 1.2k | Resistor |  |  | Tayda |  |
| R5, R9, R14 | 3 | 220k | Resistor |  |  | Tayda |  |
| R10 | 1 | 120k | Resistor |  |  | Tayda |  |
| R12, R15, R63 | 3 | 47k | Resistor |  |  | Tayda |  |
| R17, R19–22, R31, R32, R46, R48, R54, R55 | 11 | 30k | Resistor |  |  | Tayda |  |
| R18 | 1 | 22k | Resistor |  |  | Tayda |  |
| R23, R25, R27, R29, R34, R36, R38 | 7 | 15k | Resistor |  |  | Tayda |  |
| R24, R35, R40, R49 | 4 | 7.5k | Resistor |  |  | Tayda |  |
| R26, R33 | 2 | 3k | Resistor |  |  | Tayda |  |
| R30, R39, R42, R44, R50, R52 | 6 | 0R | Populate with wire jumper (resistor leg) |  |  | Tayda |  |
| R41 | 1 | 750R | Resistor |  |  | Tayda |  |
| R47 | 1 | 2k | Resistor |  |  | Tayda |  |
| R57, R74 | 2 | 1k | Resistor |  |  | Tayda |  |
| R66, R72 | 2 | 51k | Resistor |  |  | Tayda |  |
| R69–71, R73 | 4 | 10k | Resistor |  |  | Tayda |  |
| RV1–4 | 4 | 20k | Bourns 3296W |  |  | Tayda |  |
| RV5, RV11 | 2 | 10k | Bourns 3296X (side screw) |  |  | Tayda |  |
| RV6–10 | 5 | 100k | 16 mm board mount linear potentiometer |  |  | Tayda |  |
| SW1 | 1 | SW_Rotary12 | rotary switch with 12 positions |  |  | Tayda | A-1893 |
| U1 | 1 | AS3320 | VCF | Alfa |  |  |  |
| U2, U4 | 2 | TL072 | Dual operational amplifier, DIP-8 |  |  | Tayda | A-037 |
| U3 | 1 | TL074 | Quad operational amplifier, DIP-14 |  |  | Tayda | A-1138 |
| W1 | 1 | Ribbon_Cable | 14 conductor 1.27 mm pitch ribbon cable 12 cm |  |  |  |  |
| ZKN1 | 1 | Knob_MF-A04 | MF-A04 knob |  |  |  |  |
| ZKN2–6 | 5 | Knob_MF-A03 | MF-A03 knob |  |  |  |  |
| ZSC1–6 | 6 | Screw | M3 machine screw 6 mm |  |  |  |  |
| ZSP1–3 | 3 | Spacer | M3 spacer FF 10 mm |  |  |  |  |
| ZWA1–3 | 3 | Washer | M3 washer |  |  |  |  |

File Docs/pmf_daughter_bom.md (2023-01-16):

# pmf_daughter.kicad_sch BOM

Mon 16 Jan 2023 01:00:04 PM EST

Generated from schematic by Eeschema 7.0.0-rc1-unknown-00d77f624a~164~ubuntu22.04.1

**Component Count:** 37

| Refs | Qty | Component | Description | Vendor |
| ----- | --- | ---- | --- | ---- |
| J1 | 1 | Conn_02x07_Odd_Even | Generic connector, double row, 02x07, odd/even pin numbering scheme (row 1 odd numbers, row 2 even numbers), script generated (kicad-library-utils/schlib/autogen/connector/) |  |
| R1, R2, R3, R4 | 4 | 30k (typ) | Resistor | Tayda |
| R5, R6, R7, R8, R9, R10, R11, R12, R13, R14, R15, R16, R17, R18, R19, R20, R21, R22, R23, R24, R25, R26, R27, R28, R29, R30, R31, R32, R33, R34, R35, R36 | 32 | R | Resistor | Tayda |

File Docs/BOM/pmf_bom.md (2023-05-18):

# pmf.kicad_sch BOM

Fri 05 May 2023 09:03:30 PM EDT

Generated from schematic by Eeschema 7.0.2-6a45011f42~172~ubuntu22.04.1

**Component Count:** 150

| Refs | Qty | Component | Description | Manufacturer | Part | Vendor | SKU |
| ----- | --- | ---- | --- | ---- | ---- | ---- | ---- |
| C1, C3, C5, C7, C14 | 5 | 330pF | Polypropylene film capacitor, 5 mm lead spacing | WIMA | FKP2D003301D00JSSD | Tayda | 1928-1236-ND |
| C2, C4, C6, C8, C9 | 5 | 1uF | Film capacitor, 5 mm lead spacing |  |  | Tayda |  |
| C10, C11 | 2 | 10uF | Electrolytic capacitor, 2.5 mm lead spacing |  |  | Tayda | A-4349 |
| C12, C13, C15–20 | 8 | 100nF | Ceramic capacitor, 2.5 mm lead spacing |  |  | Tayda | A-553 |
| D1, D2 | 2 | 1N5817 | Schottky Barrier Rectifier Diode, DO-41 |  |  | Tayda | A-159 |
| D3, D4 | 2 | 1N4148 | Standard switching diode, DO-35 |  |  | Tayda | A-157 |
| J1 | 1 | Conn_01x06_Pin | 2.54 mm pin header, 1x6 positions |  |  |  |  |
| J2 | 1 | Conn_01x05_Pin | 2.54 mm pin header, 1x5 positions |  |  |  |  |
| J3 | 1 | Conn_01x06_Socket | 2.54 mm pin socket, 1x6 positions |  |  |  |  |
| J4 | 1 | Conn_01x05_Socket | 2.54 mm pin socket, 1x5 positions |  |  |  |  |
| J5–9, J12 | 6 | AudioJack2 | Audio Jack, 2 Poles (Mono / TS) |  |  | Tayda | A-1121 |
| J10 | 1 | Synth_power_2x5 | Pin header 2.54 mm 2x5 |  |  | Tayda | A-2939 |
| J11 | 1 | Conn_02x07_Odd_Even | Shrouded IDC header, 2x7 positions |  |  |  |  |
| J13 | 1 | Conn_02x07_Odd_Even | IDC connector, 2x7 positions |  |  |  |  |
| J14, J15, J17 | 3 | DIP-8 | 8 pin DIP socket |  |  |  |  |
| J16 | 1 | Conn_02x07_Odd_Even | 2.54 mm pin header, 2x7 positions |  |  |  |  |
| J18 | 1 | DIP-18 | 18 pin DIP socket |  |  |  |  |
| R1, R3, R8, R13 | 4 | 82k | Resistor |  |  | Tayda |  |
| R2, R6, R7, R11, R16, R56, R58–62, R64, R65, R67, R68 | 15 | 100k | Resistor |  |  | Tayda |  |
| R4 | 1 | 1.2k | Resistor |  |  | Tayda |  |
| R5, R9, R14 | 3 | 220k | Resistor |  |  | Tayda |  |
| R10 | 1 | 120k | Resistor |  |  | Tayda |  |
| R12, R15, R63 | 3 | 47k | Resistor |  |  | Tayda |  |
| R17, R19–22, R31, R32, R46, R48, R54, R55 | 11 | 30k | Resistor |  |  | Tayda |  |
| R18 | 1 | 22k | Resistor |  |  | Tayda |  |
| R23, R25, R27, R29, R34, R36, R38, R45, R53 | 9 | 15k | Resistor |  |  | Tayda |  |
| R24, R35, R40, R49 | 4 | 7.5k | Resistor |  |  | Tayda |  |
| R26, R33 | 2 | 3k | Resistor |  |  | Tayda |  |
| R30, R39, R42, R44, R50, R52 | 6 | 0R | Populate with wire jumper (resistor leg) |  |  | Tayda |  |
| R41 | 1 | 750R | Resistor |  |  | Tayda |  |
| R47 | 1 | 2k | Resistor |  |  | Tayda |  |
| R57, R74 | 2 | 1k | Resistor |  |  | Tayda |  |
| R66, R72 | 2 | 51k | Resistor |  |  | Tayda |  |
| R70, R73 | 2 | 10k | Resistor |  |  | Tayda |  |
| R75–78 | 4 | 1M | Resistor |  |  | Tayda |  |
| RV1–4 | 4 | 20k | Bourns 3296W |  |  | Tayda |  |
| RV5, RV11 | 2 | 10k | Bourns 3296X (side screw) |  |  | Tayda |  |
| RV6–10 | 5 | 100k | 16 mm board mount linear potentiometer |  |  | Tayda |  |
| SW1 | 1 | SW_Rotary12 | rotary switch with 12 positions |  |  | Tayda | A-1893 |
| U1 | 1 | TL074 | Quad operational amplifier, DIP-14 |  |  | Tayda | A-1138 |
| U2–4 | 3 | TL072 | Dual operational amplifier, DIP-8 |  |  | Tayda | A-037 |
| U5 | 1 | AS3320 | VCF | Alfa |  |  |  |
| W1 | 1 | Ribbon_Cable | 14 conductor 1.27 mm pitch ribbon cable 12 cm |  |  |  |  |
| ZKN1 | 1 | Knob_MF-A04 | MF-A04 knob |  |  |  |  |
| ZKN2–6 | 5 | Knob_MF-A03 | MF-A03 knob |  |  |  |  |
| ZSC1–6 | 6 | Screw | M3 machine screw 6 mm |  |  |  |  |
| ZSP1–3 | 3 | Spacer | M3 spacer FF 10 mm |  |  |  |  |
| ZWA1–3 | 3 | Washer | M3 washer |  |  |  |  |

## Resistors in color band order
|Value|Qty|Refs|
|----|----|----|
|1k|2|R57, R74|
|10k|2|R70, R73|
|100k|15|R2, R6, R7, R11, R16, R56, R58–62, R64, R65, R67, R68|
|1M|4|R75–78|
|1.2k|1|R4|
|120k|1|R10|
|15k|9|R23, R25, R27, R29, R34, R36, R38, R45, R53|
|2k|1|R47|
|22k|1|R18|
|220k|3|R5, R9, R14|
|3k|2|R26, R33|
|30k|11|R17, R19–22, R31, R32, R46, R48, R54, R55|
|47k|3|R12, R15, R63|
|51k|2|R66, R72|
|750R|1|R41|
|7.5k|4|R24, R35, R40, R49|
|82k|4|R1, R3, R8, R13|
|0R|6|R30, R39, R42, R44, R50, R52|

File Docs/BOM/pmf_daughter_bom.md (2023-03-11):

# pmf_daughter.kicad_sch BOM

Thu 09 Mar 2023 04:17:29 PM EST

Generated from schematic by Eeschema 7.0.0-da2b9df05c~171~ubuntu22.04.1

**Component Count:** 13

| Refs | Qty | Component | Description | Vendor |
| ----- | --- | ---- | --- | ---- |
| J1 | 1 | Conn_02x07_Odd_Even | Generic connector, double row, 02x07, odd/even pin numbering scheme (row 1 odd numbers, row 2 even numbers), script generated (kicad-library-utils/schlib/autogen/connector/) |  |
| R1–4 | 4 | 30k (typ) | Resistor | Tayda |
| R5, R7, R9, R11, R13, R15, R17, R19 | 8 | R | Resistor | Tayda |

## Resistors in color band order
|Value|Qty|Refs|
|----|----|----|
|30k (typ)|4|R1–4|
|R|8|R5, R7, R9, R11, R13, R15, R17, R19|

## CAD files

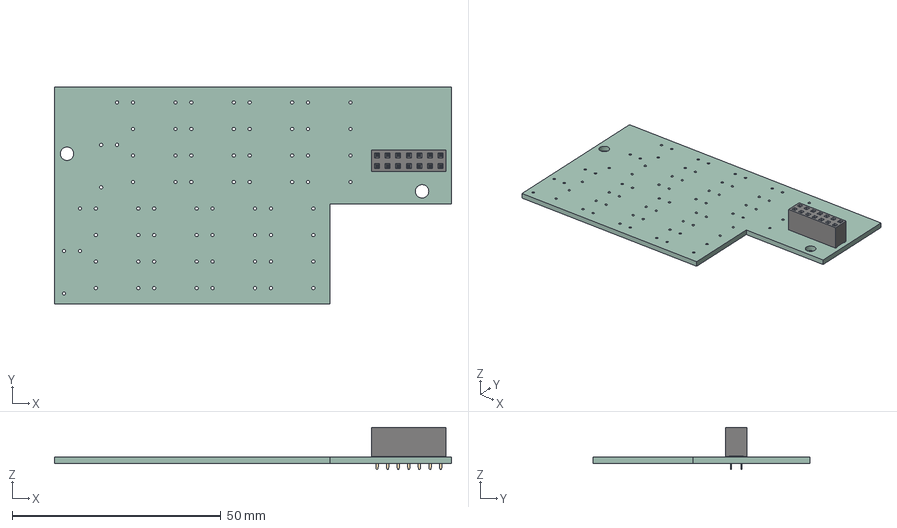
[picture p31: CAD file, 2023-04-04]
Docs/3D/pmf_daughter.step
95.0 x 52.0 x 10.1 mm
PCB

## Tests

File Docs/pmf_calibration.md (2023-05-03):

# PMF Calibration

1. Set CV offset:<br/> Set Shape to LP2 postion. With no input and no CV, turn resonance to maximum, set cutoff frequency to mid point. Observe oscillation on output. Adjust CV offset trimmer until oscillation frequency is about 250 Hz. (Trimmer counterclockwise = lower frequency.) 
2. Set V/oct trim:<br/> Send 0 V and 2 V alternately into V/oct input. Adjust V/oct trim until frequency ratio is 2:1. 
3. Disconnect V/oct input. Repeat step 1.
4. Set resonance to minimum, cutoff frequency to maximum.
5. Measure and note voltages at input test point corresponding to two input voltages. Calculate the difference between these voltages.
6. Measure voltages at LP1 test point. Adjust Gain 1 trimmer until voltage difference here is the same as voltage difference from step 5.
7. Repeat step 6 for LP2–4 test points and Gain 2–4 trimmers.

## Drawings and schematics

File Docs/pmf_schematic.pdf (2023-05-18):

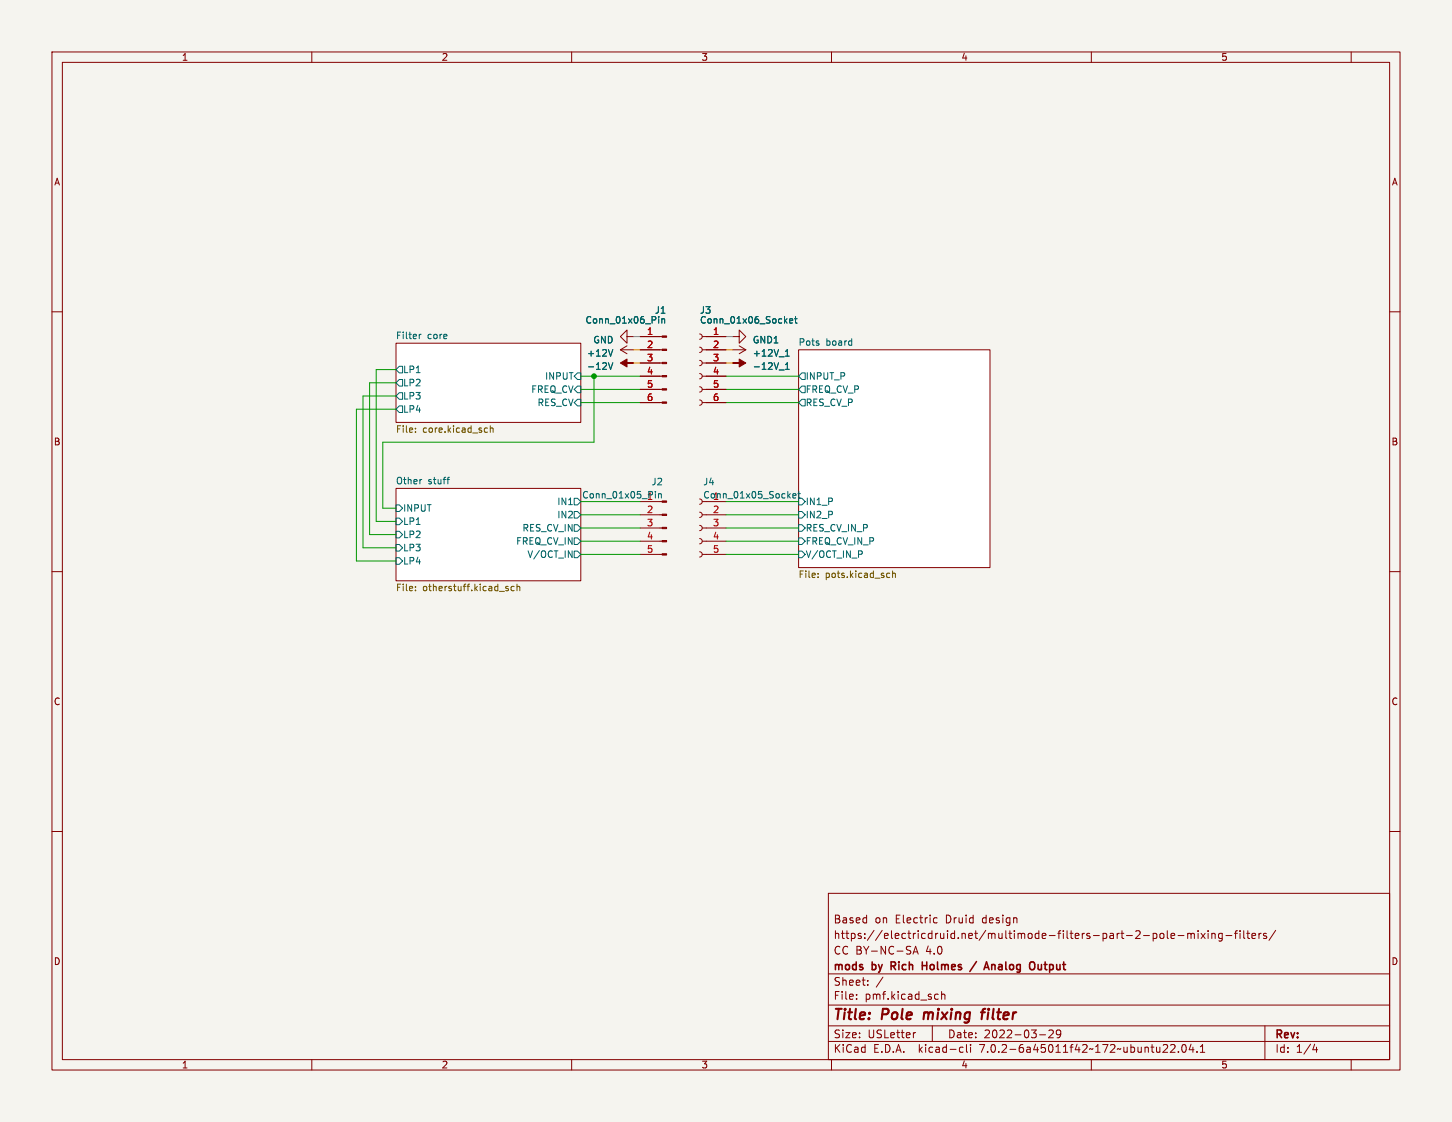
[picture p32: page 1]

LP1 Filter core File: core.kicad_sch

Pots board File: pots.kicad_sch RES_CV_IN

INPUT Other stuff File: otherstuff.kicad_sch

https://electricdruid.net/multimode-filters-part-2-pole-mixing-filters/ Based on Electric | Druid | design

E.D.A. kicad-cli 7.0.2-6a45011f42~172~ubuntu22.04.1 Size: USLetter Rev: | D Date: 2022-03-29 KiCad

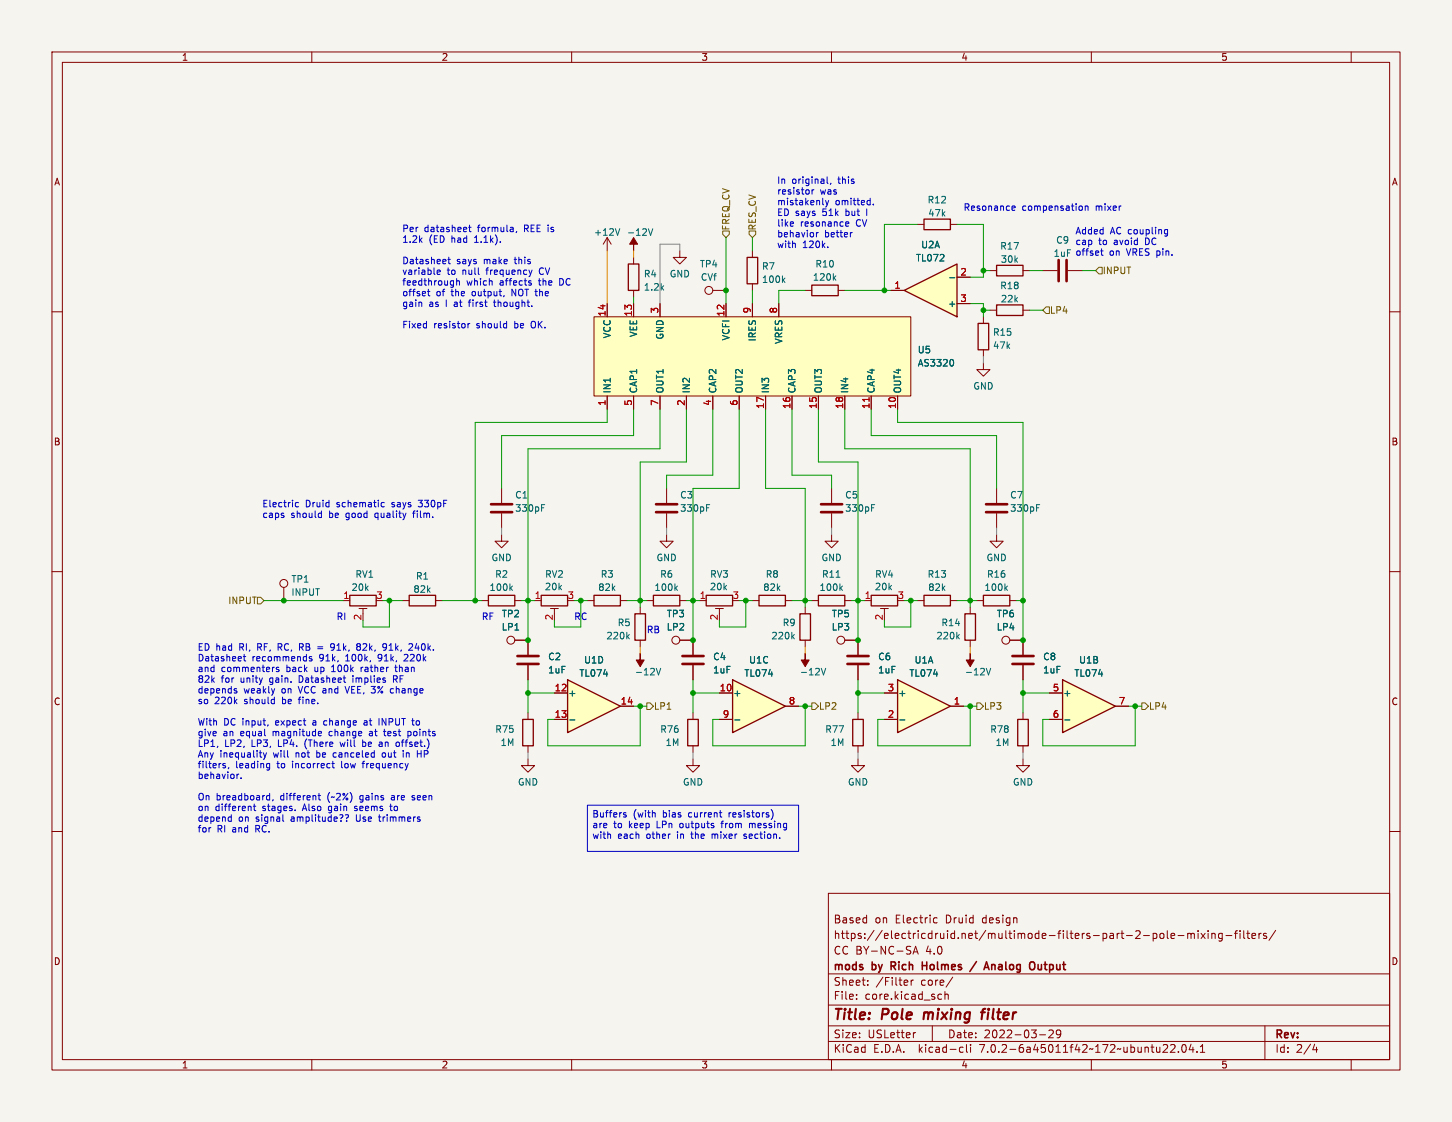
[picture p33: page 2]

Added AC coupling
cap to avoid DC

offset on VRES pin. C2

offset of the output, NOT the

caps should be good quality film.

82k for unity gain. Datasheet implies RF
depends weakly on VCC and VEE, 3% change
so 220k should be fine. With DC input, expect a change at INPUT to

for RI and RC.

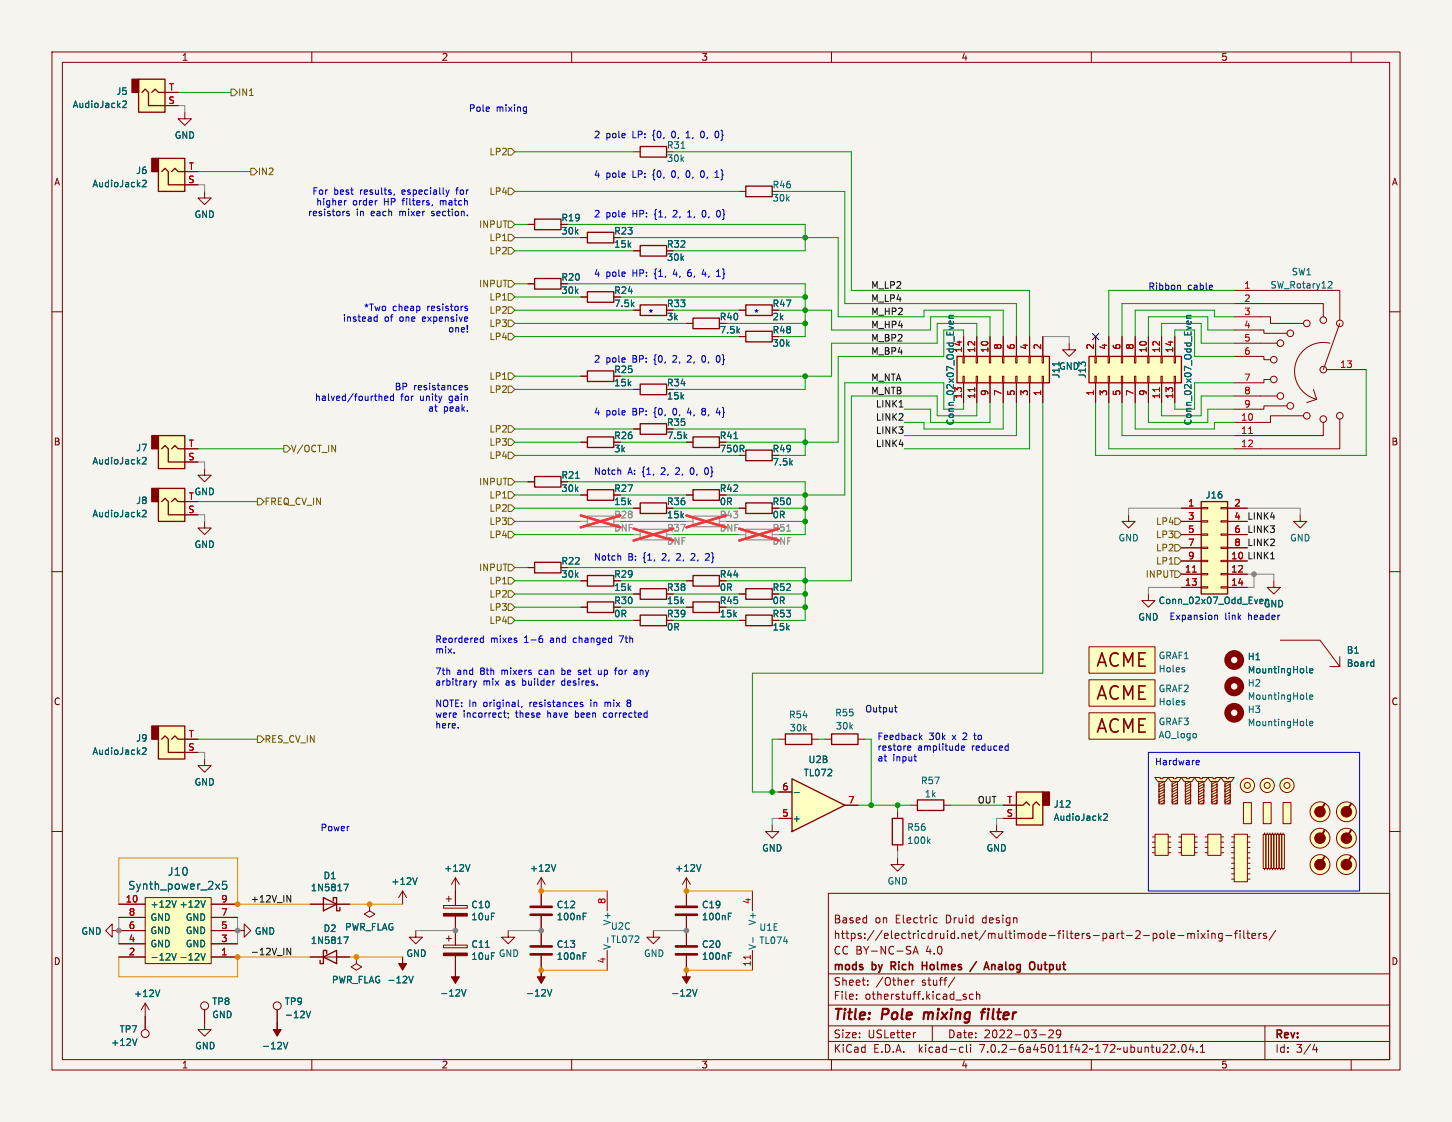
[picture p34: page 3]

2 pole HP: {1, 2, 1, 0, 0} Notch B: {1, 2, 2, 2, 2} Power

*Two cheap resistors
instead of one expensive

9 J13 Conn_02x07_Odd_Even H3 MountingHole B1Board H1 MountingHole GND ACME GRAF3 AO_logo

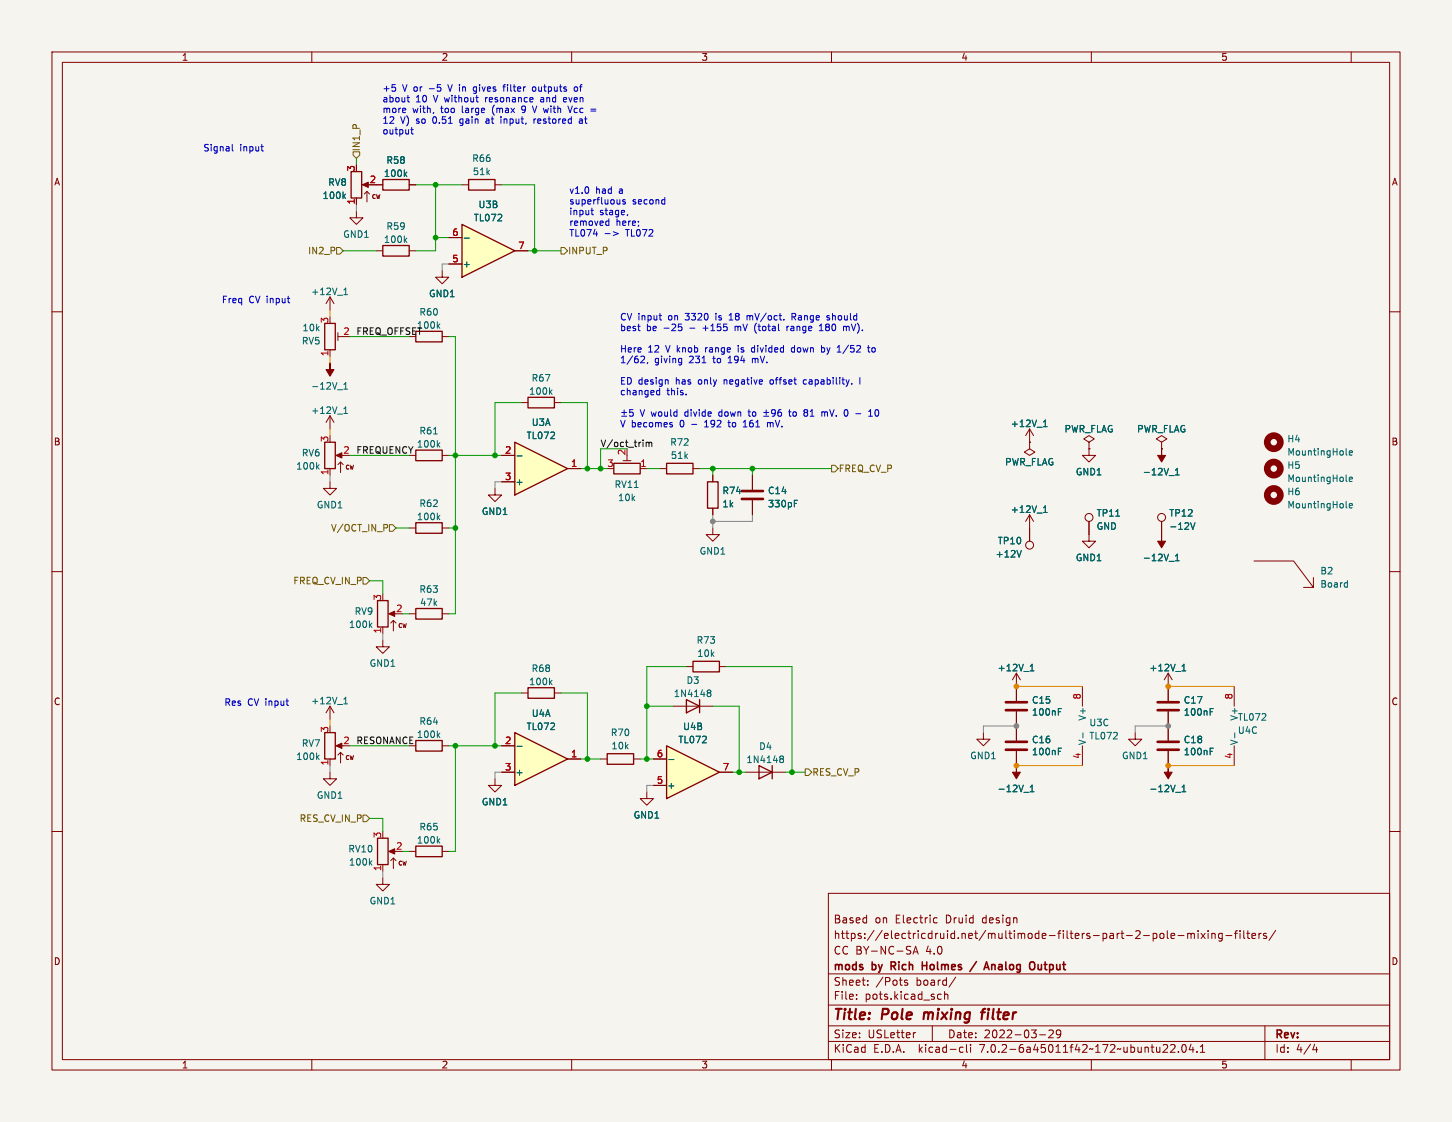
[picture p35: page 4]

INPUT_P RES_CV_IN_P
Freq CV input Res CV input

https://electricdruid.net/multimode-filters-part-2-pole-mixing-filters/ Based on Electric | Druid | design

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

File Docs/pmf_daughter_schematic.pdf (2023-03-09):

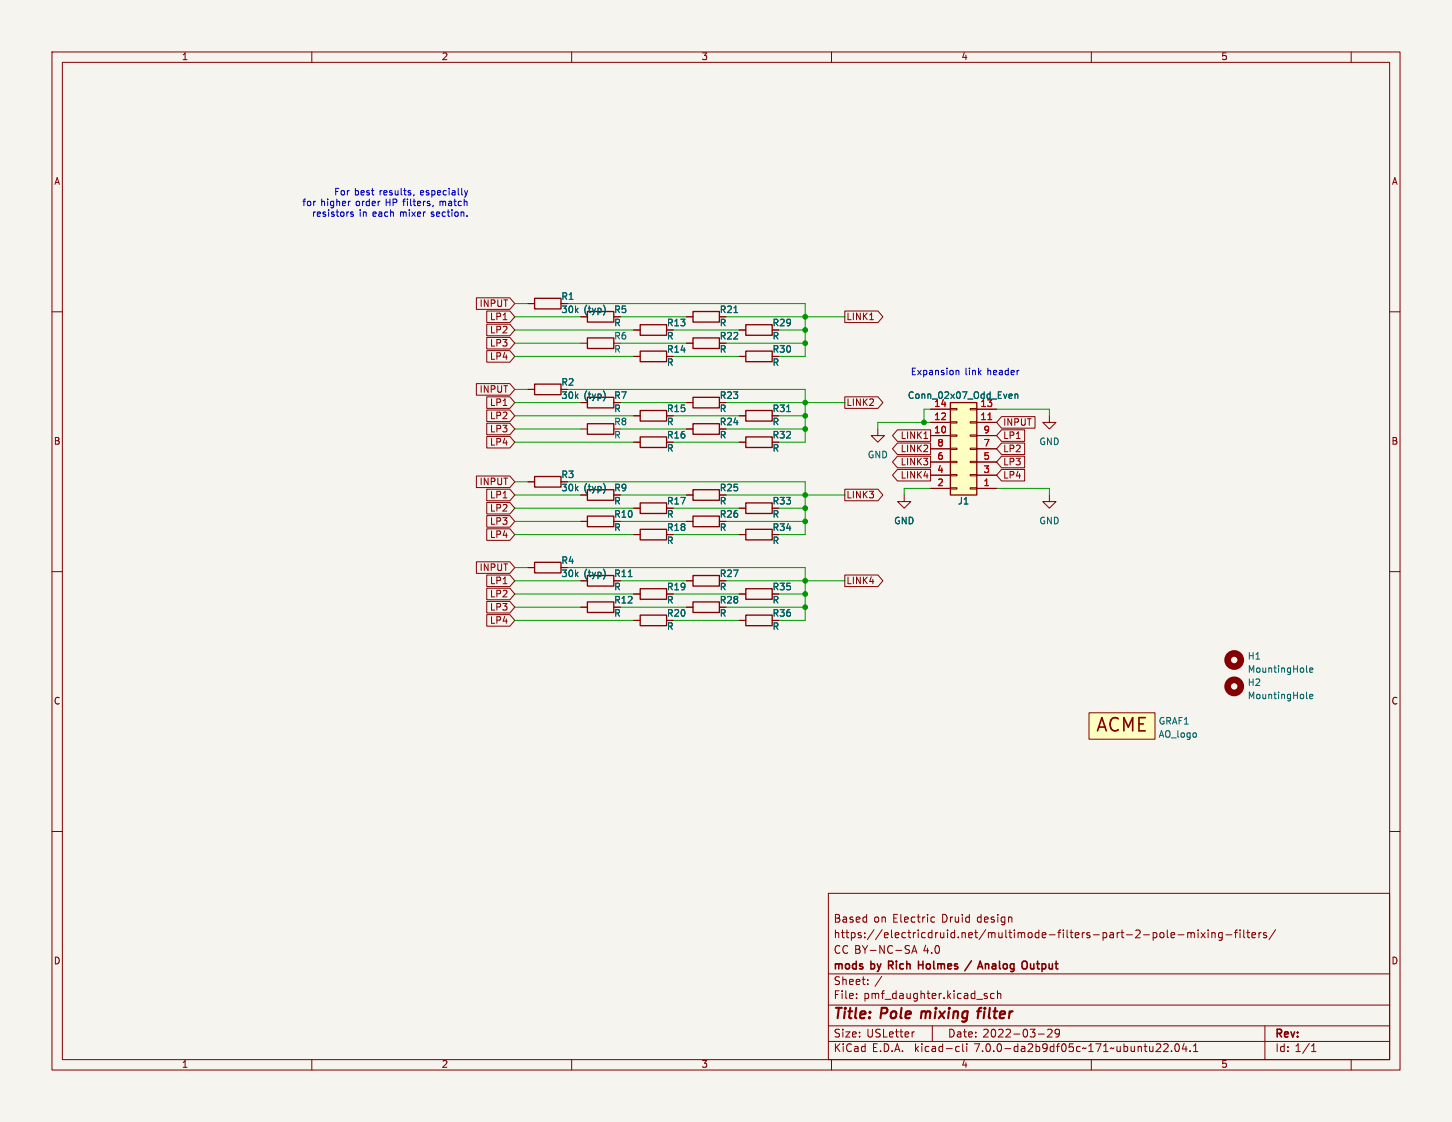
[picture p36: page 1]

for higher order HP filters, match

https://electricdruid.net/multimode-filters-part-2-pole-mixing-filters/ Based | on Electric | Druid | design

E.D.A. kicad-cli 7.0.0-da2b9df05c~171~ubuntu22.04.1 Size: USLetter Rev: | D Date: 2022-03-29 KiCad

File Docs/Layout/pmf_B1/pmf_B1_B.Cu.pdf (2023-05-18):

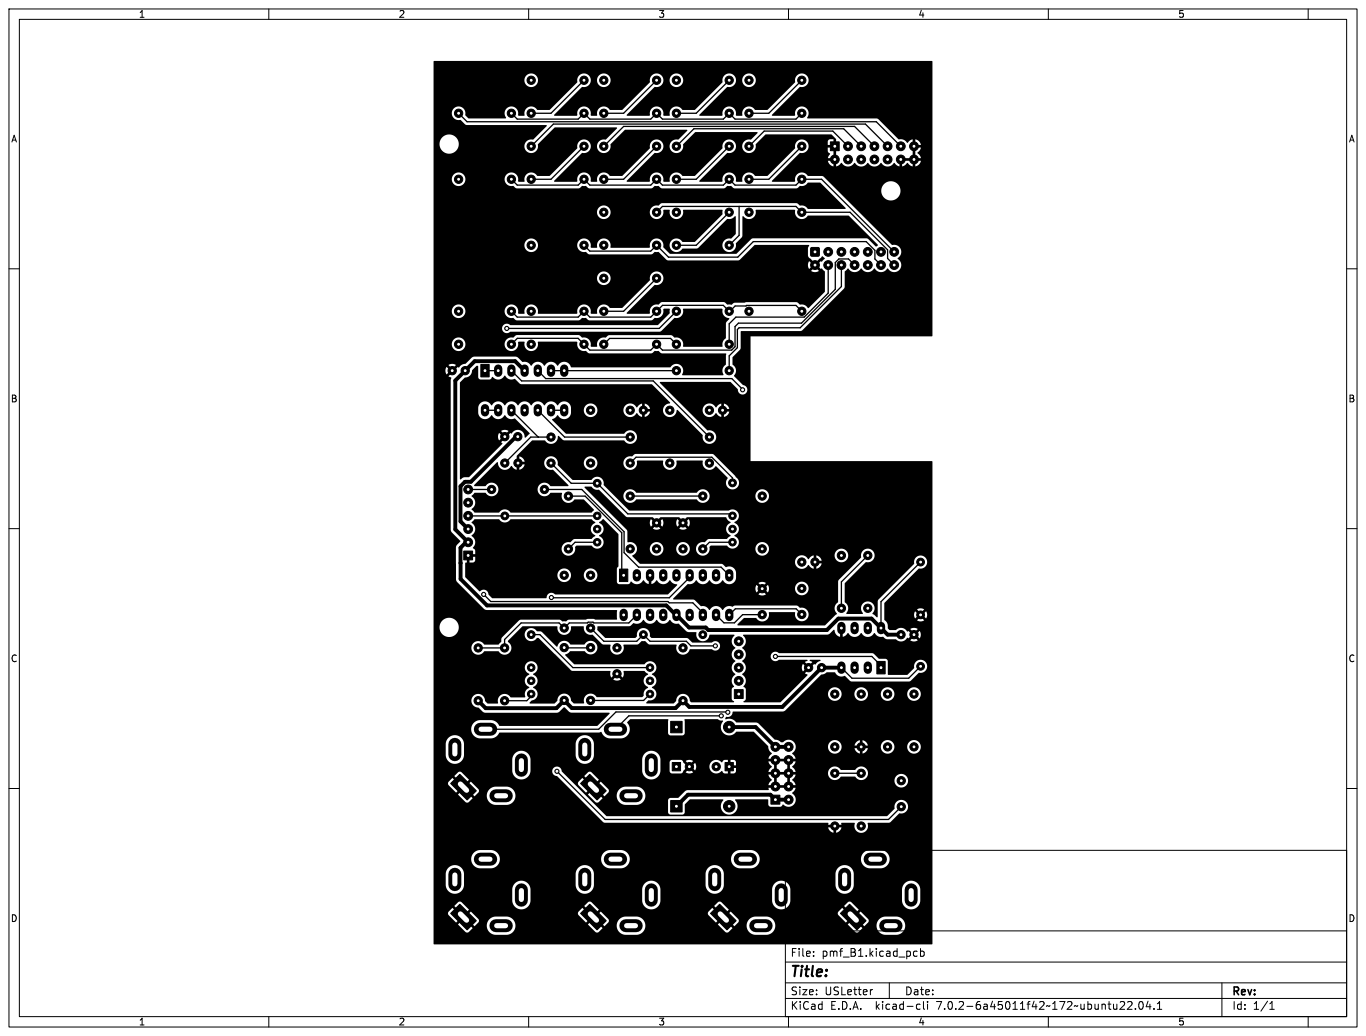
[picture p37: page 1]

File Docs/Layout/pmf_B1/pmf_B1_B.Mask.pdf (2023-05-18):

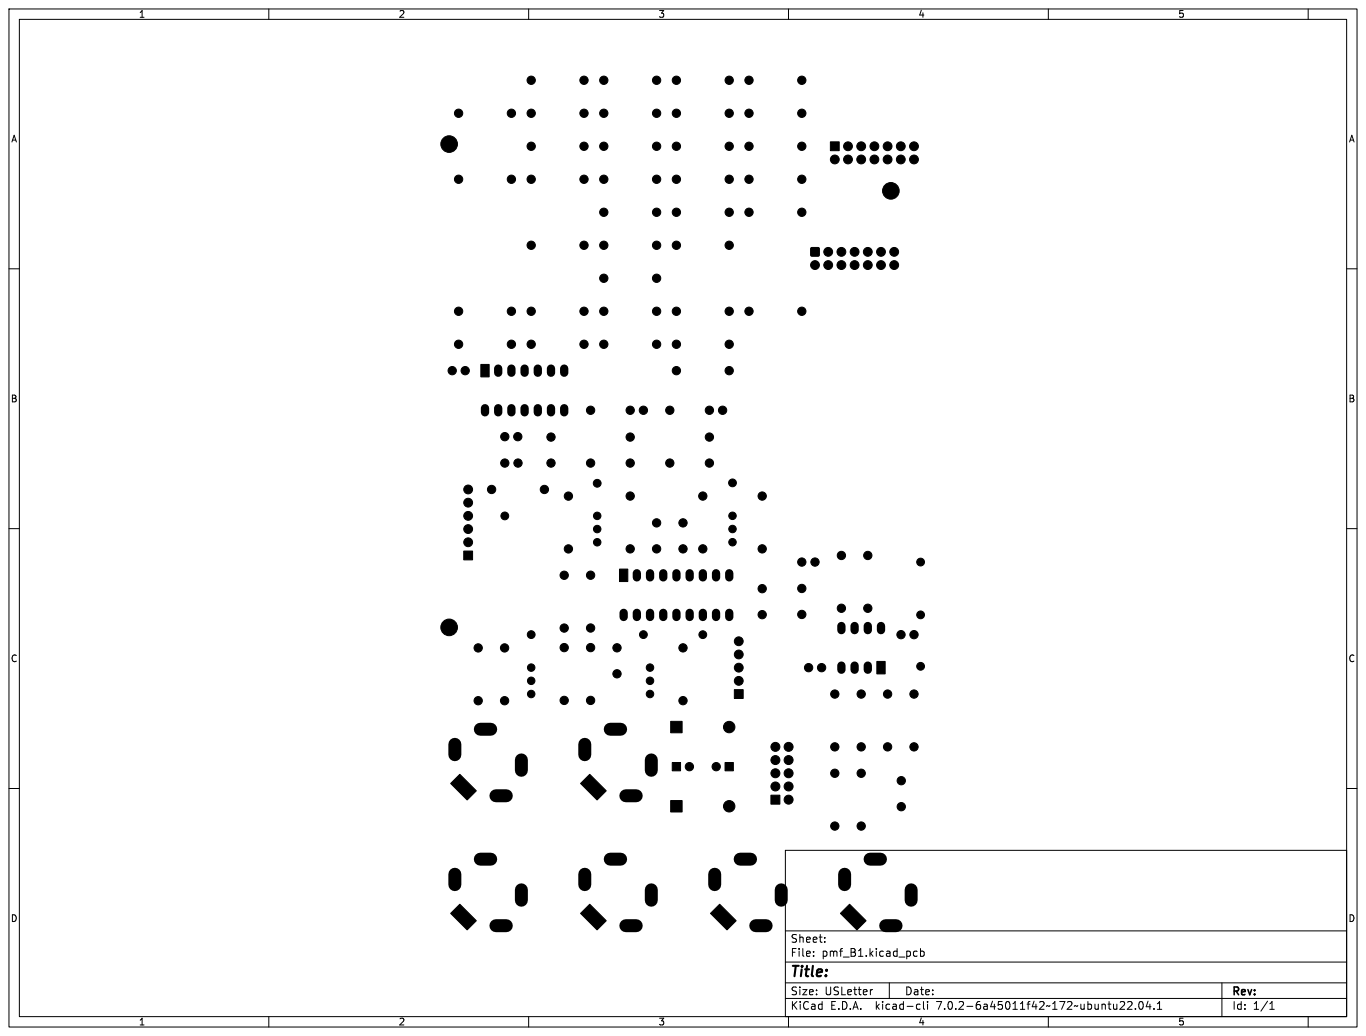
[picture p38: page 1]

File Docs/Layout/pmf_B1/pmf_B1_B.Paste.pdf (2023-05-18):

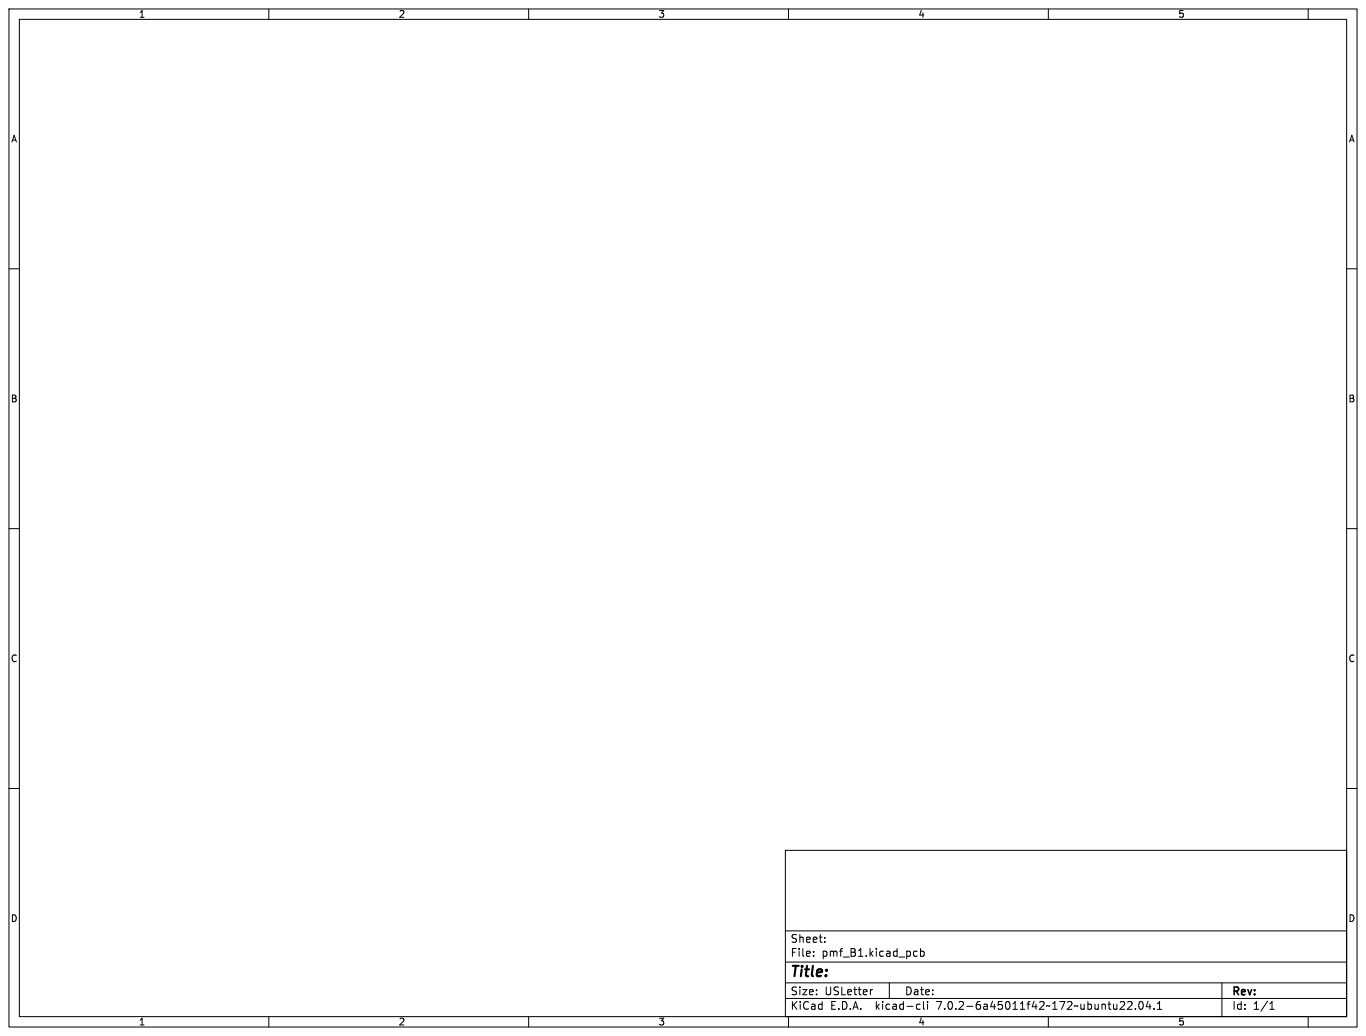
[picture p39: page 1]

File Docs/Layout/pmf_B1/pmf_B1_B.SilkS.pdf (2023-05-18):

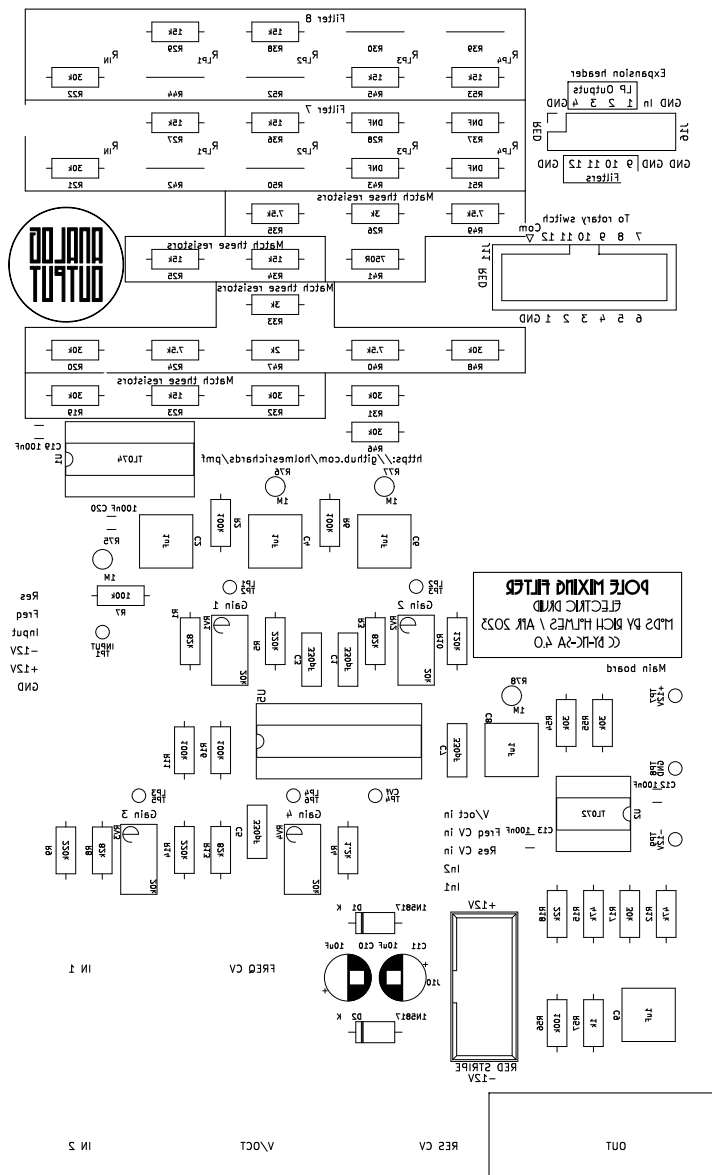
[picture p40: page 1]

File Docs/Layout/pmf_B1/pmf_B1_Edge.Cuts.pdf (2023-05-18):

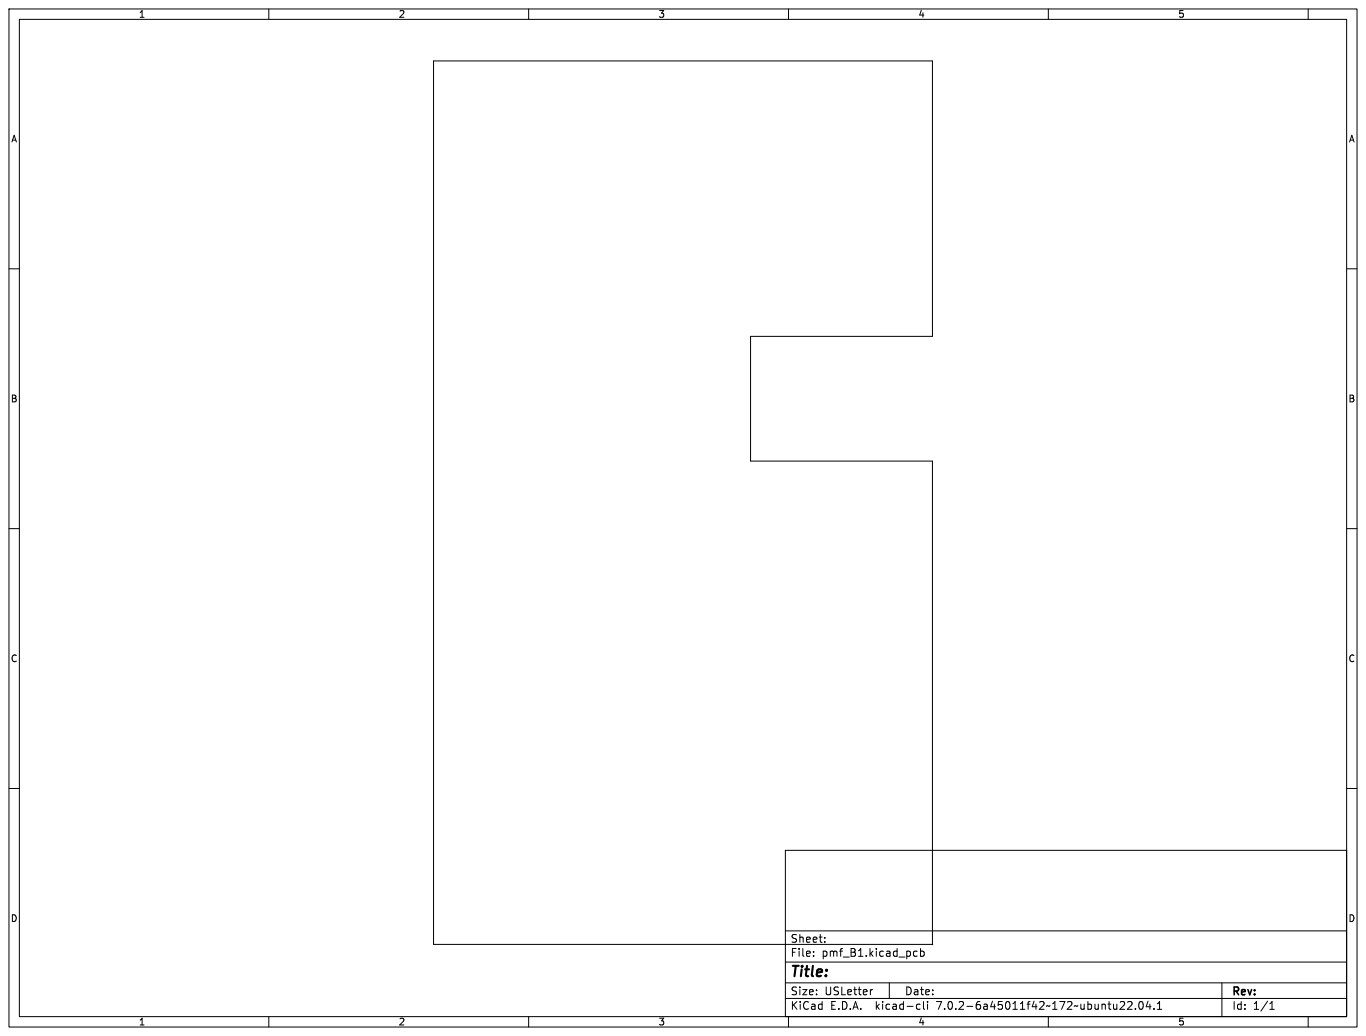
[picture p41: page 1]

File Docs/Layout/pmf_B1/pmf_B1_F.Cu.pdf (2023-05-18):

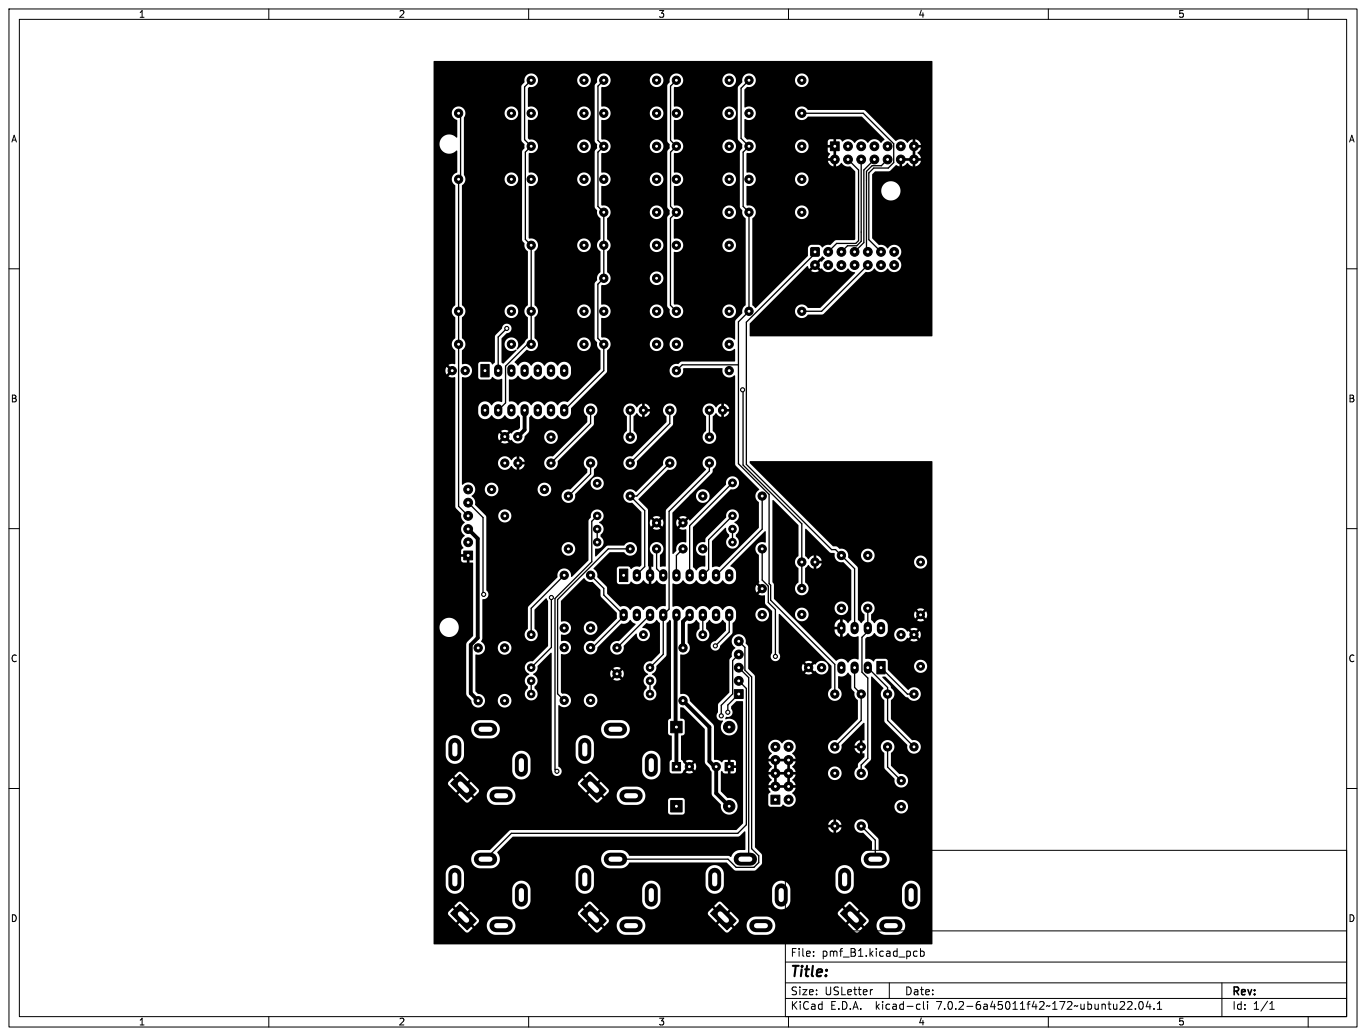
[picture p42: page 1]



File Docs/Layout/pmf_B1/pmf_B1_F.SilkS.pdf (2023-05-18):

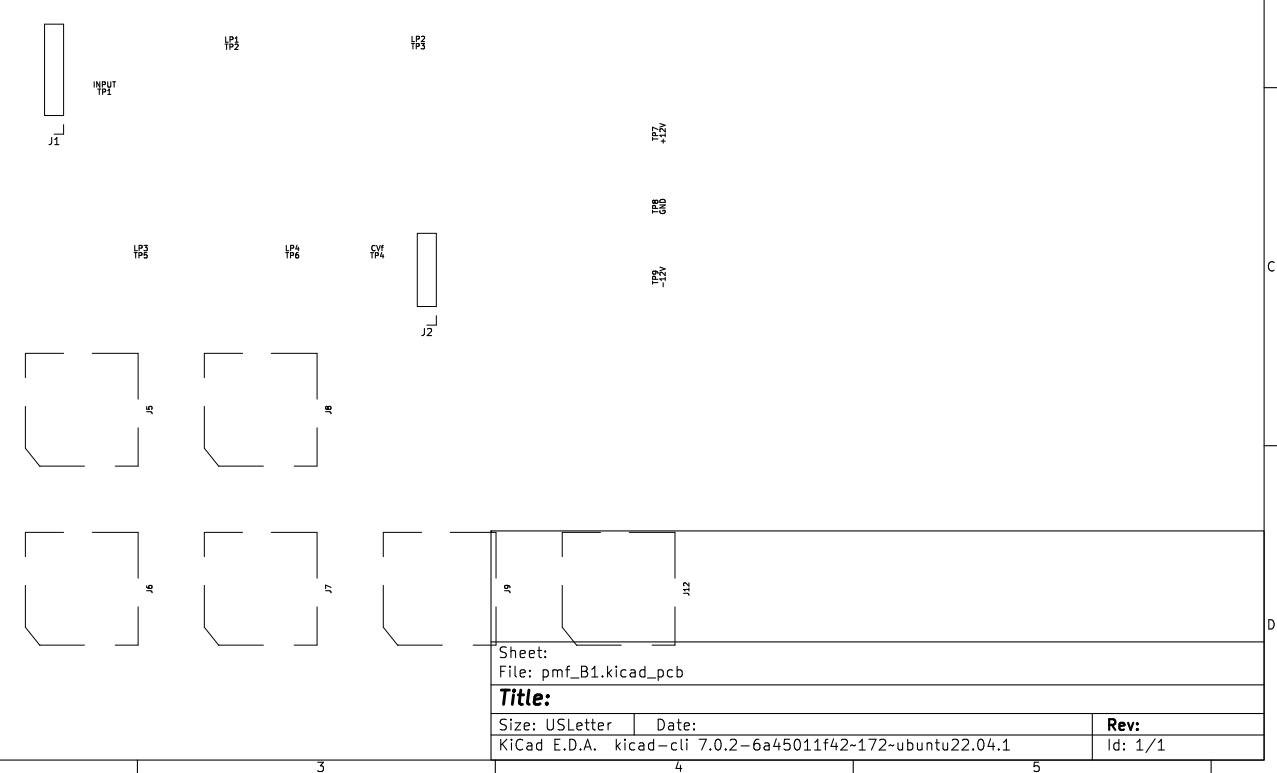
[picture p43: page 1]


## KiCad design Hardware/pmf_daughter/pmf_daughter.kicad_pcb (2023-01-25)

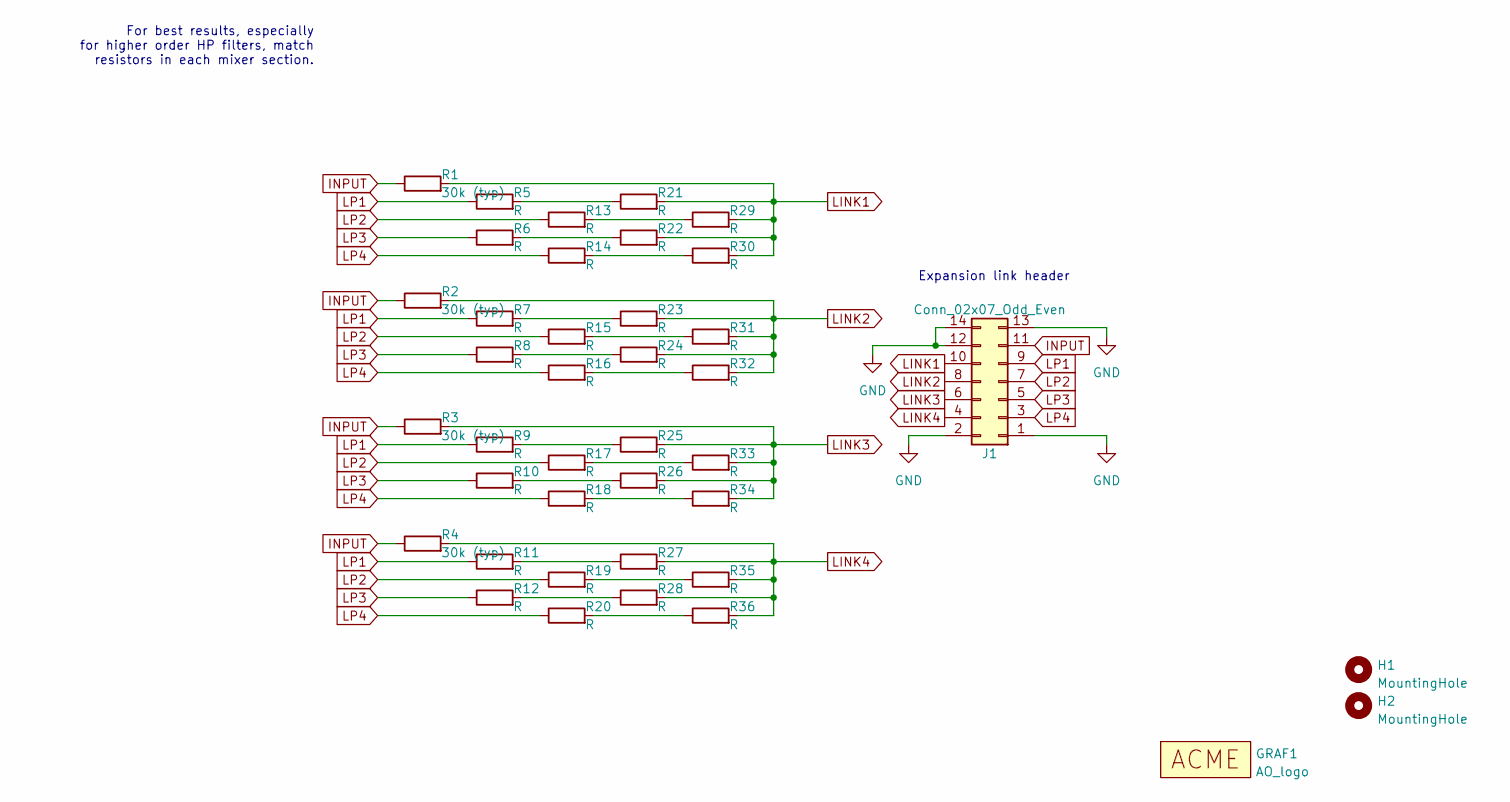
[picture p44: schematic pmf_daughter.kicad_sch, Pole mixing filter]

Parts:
GRAF1: AO_logo; analogoutput_12mm
H1, H2: MountingHole; MountingHole_3.2mm_M3
J1: Conn_02x07_Odd_Even; PinSocket_2x07_P2.54mm_Vertical
R1, R2, R3, R4: 30k (typ); R_Axial_DIN0207_L6.3mm_D2.5mm_P10.16mm_Horizontal
R5, R6, R7, R8, R9, R10, R11, R12, R13, R14, R15, R16, R17, R18, R19, R20, R21, R22, R23, R24, R25, R26, R27, R28, R29, R30, R31, R32, R33, R34, R35, R36: R; R_Axial_DIN0207_L6.3mm_D2.5mm_P10.16mm_Horizontal

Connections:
GND: J1.1, J1.2, J1.12, J1.13, J1.14
INPUT: J1.11, R1.1, R2.1, R3.1, R4.1
LINK1: J1.10, R1.2, R21.2, R22.2, R29.2, R30.2
LINK2: J1.8, R2.2, R23.2, R24.2, R31.2, R32.2
LINK3: J1.6, R3.2, R25.2, R26.2, R33.2, R34.2
LINK4: J1.4, R4.2, R27.2, R28.2, R35.2, R36.2
LP1: J1.9, R5.1, R7.1, R9.1, R11.1
LP2: J1.7, R13.1, R15.1, R17.1, R19.1
LP3: J1.5, R6.1, R8.1, R10.1, R12.1
LP4: J1.3, R14.1, R16.1, R18.1, R20.1
unnamed: R10.2, R26.1
unnamed: R11.2, R27.1
unnamed: R12.2, R28.1
unnamed: R13.2, R29.1
unnamed: R14.2, R30.1
unnamed: R15.2, R31.1
unnamed: R16.2, R32.1
unnamed: R17.2, R33.1
unnamed: R18.2, R34.1
unnamed: R19.2, R35.1
unnamed: R20.2, R36.1
unnamed: R5.2, R21.1
unnamed: R6.2, R22.1
unnamed: R7.2, R23.1
unnamed: R8.2, R24.1
unnamed: R9.2, R25.1

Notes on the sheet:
Expansion link header
For best results, especially for higher order HP filters, match resistors in each mixer section.

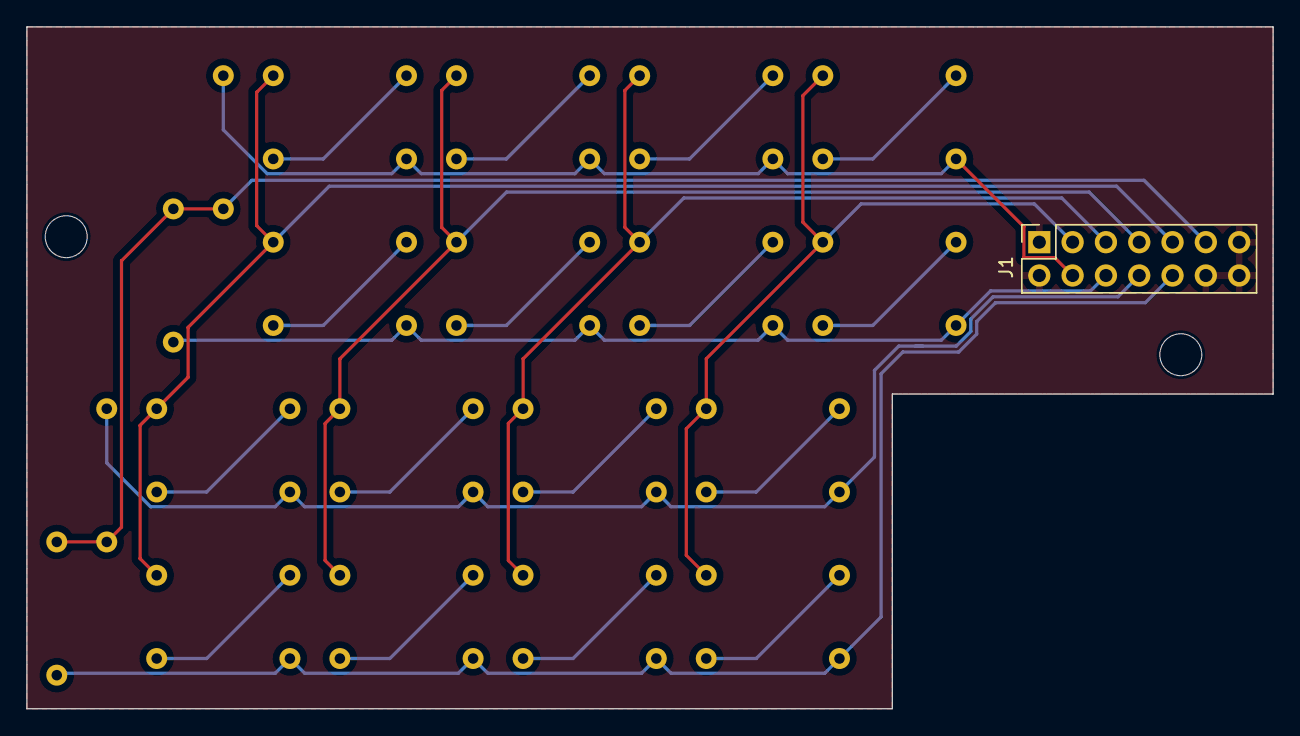
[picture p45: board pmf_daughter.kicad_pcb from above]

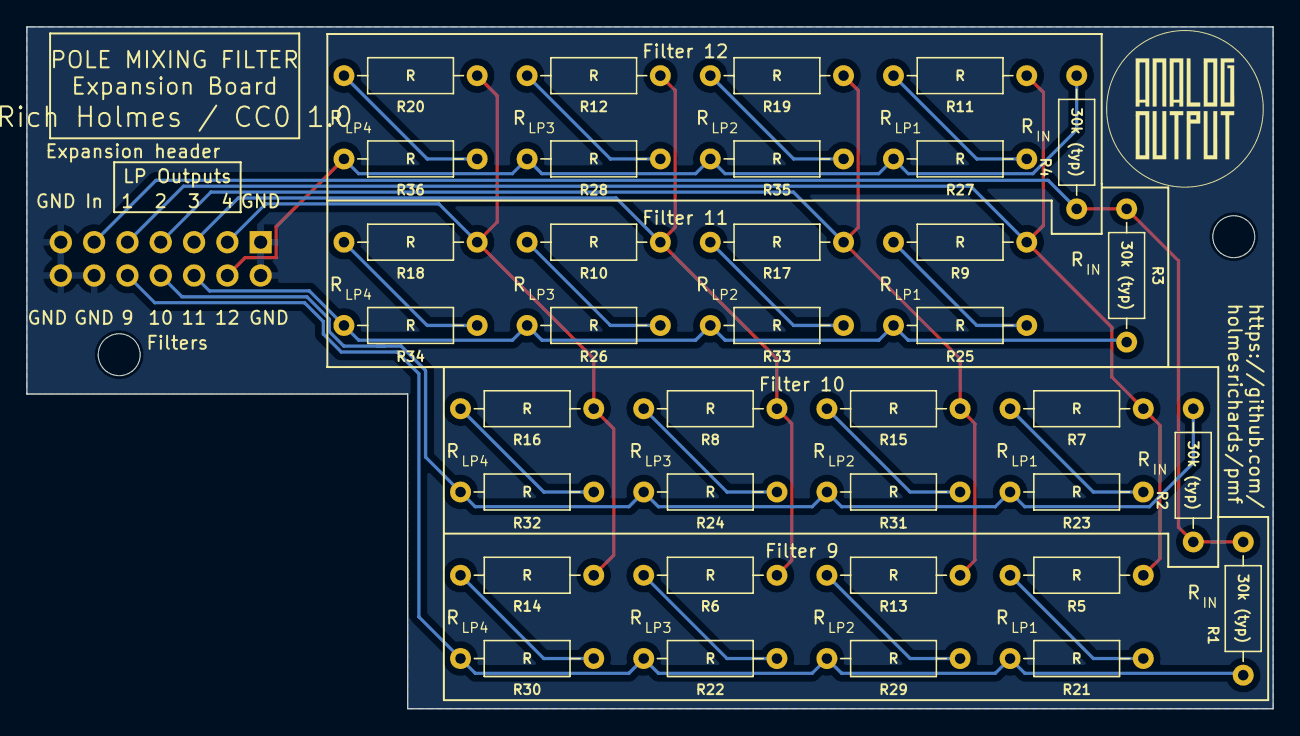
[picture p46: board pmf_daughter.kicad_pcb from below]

Board: 2 copper layers, 95.0 x 52.0 mm, 40 parts (37 on the bottom side), 26 nets.

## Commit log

2023-01-16 Initial version
    [core.kicad_sch, otherstuff.kicad_sch, pmf.kicad_sch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]
2023-01-17 Font change; GND instead of NC on d-board
    [pmf_daughter.kicad_pcb, pmf_daughter.kicad_sch]
2023-01-19 Re-invert input
    [pots.kicad_sch]
2023-01-19 Reorganize filter core schematic
    [core.kicad_sch]
2023-01-19 Resistor matching labels
2023-01-19 Rename libraries
    [core.kicad_sch, otherstuff.kicad_sch, pmf.kicad_sch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]
2023-01-19 Larger resistor for resonance input
    [core.kicad_sch, otherstuff.kicad_sch, pmf.kicad_sch]
2023-01-20 Removed R_EE trimmer
    [core.kicad_sch]
2023-01-20 Add missing resistor
    [pots.kicad_sch]
2023-01-20 Reposition pot board trimmers; ±12 V range for CV offset
    [pots.kicad_sch]
2023-01-21 Remove VRES bias
    [core.kicad_sch, otherstuff.kicad_sch, pots.kicad_sch]
2023-01-22 Reduce amplitude at input and restore at output
    [otherstuff.kicad_sch, pots.kicad_sch]
2023-01-24 Lower gain at input and higher at output; better justification for AC coupling at compensation mixer
    [pots.kicad_sch]
2023-01-25 Large attenuation and amplification
    [otherstuff.kicad_sch, pots.kicad_sch]
2023-01-25 Gain variation even with matched resistors
2023-01-25 CVf test point; disambiguate heirarchical symbols
    [core.kicad_sch, otherstuff.kicad_sch, pmf.kicad_sch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]
2023-01-25 Bigger trimmers for RC; slightly move expansion header
    [core.kicad_sch, pmf_daughter.kicad_pcb, pots.kicad_sch]
2023-01-26 Hardware symbols test
    [core.kicad_sch, otherstuff.kicad_sch, pots.kicad_sch]
2023-01-29 Return to smaller trimmer values; make core schematic clearer; restore munged footprints
    [core.kicad_sch, otherstuff.kicad_sch, pots.kicad_sch]
2023-02-12 Pre fab tweaks, Gerbers, BOM
    [core.kicad_sch, otherstuff.kicad_sch, pmf.kicad_sch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]
2023-02-13 Text boxes
    [core.kicad_sch, otherstuff.kicad_sch, pots.kicad_sch]
2023-02-14 Knobs, new hardware refs, improved BOM format
    [otherstuff.kicad_sch]
2023-03-11 rm omit from BOM and board
    [otherstuff.kicad_sch]
2023-03-12 reduce heirarchy; docs
    [core.kicad_sch, otherstuff.kicad_sch, pmf.kicad_sch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]
2023-03-31 Calibration doc
2023-03-31 Global labels to heir, fixing input bug; buffer LP1-4; more clearance for rot switch
    [core.kicad_sch, otherstuff.kicad_sch, pmf.kicad_sch]
2023-04-04 Docs; add bias current resistors
    [core.kicad_sch, otherstuff.kicad_sch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]
2023-05-03 PCB updates; docs
    [pmf_B1-CmtUser.gbr, pmf_B1-CuBottom.gbl, pmf_B1-CuTop.gtl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]
2023-05-05 Second stage on input is probably counterproductive
    [pots.kicad_sch]
2023-05-05 Remove second input stage
    [pots.kicad_sch]
2023-05-18 Docs; rm Gerbers pending resolution of kikit problem

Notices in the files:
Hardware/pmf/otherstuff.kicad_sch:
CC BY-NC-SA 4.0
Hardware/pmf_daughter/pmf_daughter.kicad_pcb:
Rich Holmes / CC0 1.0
